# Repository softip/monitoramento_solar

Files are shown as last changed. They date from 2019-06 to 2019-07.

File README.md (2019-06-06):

# Monitoramento Solar

Matéria: IE309X 

Nome                       |RA	 
---------------------------|------
Eloísa A. N. Matthiesen	   |208929
Rafael Augusto Pedriali    |190742
Dimas Augusto Mendes Lemes |163660 
Ivan Paulino Pereira       |262125	

## Introdução 
Diante das novas formas de se usarem os dispositivos eletrônicos, novas tecnologias foram sendo desenvolvidas e adaptadas para as novas funcionalidades. A busca por maiores taxas de transmissão de dados, visando formas de conexão que minimizem custos de projeto, que diminuam a necessidade de alta potência na transmissão e aumentem as áreas de cobertura sendo confiáveis vêm produzindo resultados nos meios industrial e acadêmico. Estas tecnologias estão relacionadas ao conceito de Internet das Coisas. 

A Internet das Coisas, representada pela sigla IoT (Internet of Things), é definida de acordo com a União Internacional das Telecomunicações como uma infraestrutura global que habilita serviços avançados por meio da interconexão entre coisas, ditas físicas ou virtuais, com base nas tecnologias de informação e comunicação. Ou seja, a ideia é conectar coisas, objetos do dia-a-dia, dotando-os de capacidade de processar dados. Dessa forma, uma solução em IoT deve atender a três pré-requisitos. São eles: Reconhecimento de dados, Conexão a uma rede e a Capacidade de processar os dados sem que haja interferência humana. 
A aplicação de IoT pode trazer benefícios aos cidadãos, à gestão pública, como questões envolvendo segurança, transporte e eficiência energética, que também é benéfica ao meio ambiente. A questão ambiental também é um fator relevante devido às fontes de energia renováveis, dentre elas a energia solar. 
A energia solar pode ser usada como fonte de energia elétrica e tem a vantagem de ser uma das mais limpas formas de geração de energia existentes no mundo. É utilizada em tecnologias como arquitetura solar, fotossíntese artificial, aquecimento solar, energia heliotérmica e energia solar fotovoltaica. Especificamente no caso da energia solar fotovoltaica, a luz do sol é captada por meio de painéis solares que tem por finalidade realizar a conversão da energia luminosa em energia elétrica. Nesse processo é possível criar uma rede IoT em que os painéis solares estejam conectados a dispositivos de comunicação que traduzam, por exemplo, ao consumidor a capacidade de geração de energia elétrica do sistema, buscando minimizar custos. 

## Objetivo 
Desenvolver uma Rede de Sensor Sem Fio (RSSF) para monitoramento da geração de energia em painéis solares. Serão coletados os valores da tensão e corrente, enviando-os para um banco de dados, sendo possível ter o completo gerenciamento dos dados coletados. A comunicação será realizada por meio de módulos de comunicação BE900.

## Material 

Item |Uni |Quant |Descrição                          |Unitário   |Total
:---:|:--:|:----:|-----------------------------------|----------:|--------:
1    |UN  |2     |Módulos de comunicação BE900       |R$   180,00|R$ 360,00
2    |UN  |1     |UARTsBee                           |R$   127,00|R$ 127,00
3    |UN  |2     |Antenas omnidireccional de 2,15 dBi|R$    29,00|R$  58,00
4    |UN  |1     |Placa de desenvolvimento DK 107    |R$   165,00|R$ 165,00
5    |UN  |1     |Raspberry Pi                       |R$   290,00|R$ 290,00
6    |UN  |1     |Sensor Allegro ACS712              |R$    26,90|R$  26,90
7    |UN  |1     |Amplificador LM324                 |R$    12,00|R$  12,00
### Total                              R$ 1.038,90 

## Cronograma
Ativid. \ Mês                      |Março |Abril |Maio  |Junho
-----------------------------------|:----:|:----:|:----:|:----:
Estudo do Tema                     |X     |      |      |
Elaboração do Projeto              |X     |      |      |
Seleção e Obtenção dos Componentes |X     |      |      |
Montagem                           |X     |X     |X     |  
Desenvolvimento do Software        |X     |X     |X     |
Testes                             |      |      |X     |
Elaboração do Relatório Final      |      |      |      |X
Apresentação Final                 |      |      |      |X

## Questão a)

### Nível 7 – Negócio
O negócio contemplado nesse projeto foi a geração fotovoltaica construída na Unicamp, um subprojeto do Campus Sustentável. Ao todo será instalado 573 kWp de geração no campus, focaremos na microgeração instalada na FEEC - Faculdade de Engenharia Elétrica e de Computação, com 97 kWp.
### Nível 6 – Exibição
Nesse nível irá apresentar gráficos para os estudantes e funcionários da Unicamp, mostrando o nível de geração da FEEC e o quanto isso significa no uso total da energia do campus. Nesse nível é necessário definir quais são as regras do negócio, quais os alarmes e alertas que serão criados durante o projeto.
### Nível 5 – Abstração
A abstração é feita com a ajuda de um especialista, qual a tensão nominal da placa fotovoltaica, qual a eficiência da mesma? Essas questões são resolvidas utilizando um especialista. No caso do projeto, o especialista pode ser algum professor com conhecimento na área que pode ajudar o grupo.
### Nível 4 – Storage
O armazenamento dos dados, no primeiro momento, será feito localmente, mas tendo a possibilidade de enviar os dados para a nuvem. É preciso definir a quantidade de dados que será armazenada e com qual frequência.
### Nível 3 – Borda
O elemento de borda é responsável pela conexão da RSSF à Internet. Ele será realizado através de uma Raspberry Pi 3.
### Nível 2 – Conectividade
A conectividade será feita por meio de uma RSSF, com módulos de comunicação compostos por um microcontrolador Atmega328 e um transceptor CC1101. Uma placa de desenvolvimento DK107 no Nó Sensor e um programador UARTsBee para a Estação Rádio Base (ERB).
### Nível 1 – Nó Local Sensor/Atuador
Utilizaremos a plataforma Radiuino para criar os firmwares dos Nós. Para medir a tensão da placa será usado o DK107, em conjunto com um divisor de tensão, e a corrente será medida através de um sensor de efeito hall, Allegro ACS712.
Nível 0 – Coisas
A coisa desse projeto é a placa fotovoltaica, utilizada na microgeração da FEEC.

## Questão b)

### b.1) 
As variáveis da "coisa" que devem ser medidas são a corrente e a tensão do painel fotovoltaico durante o tempo, para assim poder calcular a energia produzida pela mesma.

### b.2) 
Primeiramente, são analisadas as especificações dos painéis solares, pois é necessário saber a faixa de operação do equipamento para a adequada elaboração e desenvolvimento do projeto.

Painel                              |Potência (W)|Tensão (V)|Corrente (A)
------------------------------------|:----------:|:--------:|:----
Yingli JS150                        |150         |18.5      |8.12
Kyocera KD140SX                     |140         |17.7      |7.91
Komaes KMP150                       |150         |18.28     |8.21
Canadian Solar CS6K 260P            |260         |30.40     |8.56
Canadian Solar CS6K 275P            |275         |31        |8.88
UPSolar M150P                       |150         |18.06     |8.07
UPSolar M315P                       |315         |36.5      |8.63

Com esta tabela é possível dimensionar um array  de placas que pode para ser projetado seguindo as especificações do sensor Allegro ACS712, o qual é apresentado no próximo item.
 
### b.3) 
Após realizar uma pesquisa de mercado foi observado que a melhor opção para poder realizar as medidas da corrente é com o sensor Allegro ACS712, o qual pode ser visto na figura a seguir.


 
Este sensor é classificado como invasivo, ou seja, é necessário abrir o circuito para fazer a medição.  Além disso, ao adicioná-lo ao circuito provoca uma baixa queda de tensão durante a medição, devido a sua resistência interna ser de apenas 1,2 mOhm. Possui fundo de escala de -30 A até 30 A tanto para corrente contínua como para alternada, com uma sensibilidade de aproximadamente 0,066 mV/A. A medição ocorre por meio do efeito hall para detectar o campo magnético gerado pela corrente.
 
A de tensão a ser medida será realizada diretamente, mas como a entrada pino de medição não deve possuir uma tensão maior do que 5V. Então será realizado um divisor de tensão para abaixar a tensão gerada. Este circuito é isulatrado a fingura a seguir.



O capacitor tem o objetivo de eliminar possíveis ruídos na medição.

Outra medida a ser informada é a temperatura, pois apesar do aumento na irradiação solar sobre a placa fotovoltaica fornecer mais energia, o aumento da temperatura da placa danifica-a. O sensor utilizado para a medição é o LM35DZ encapsulado (proteção contra fatores adversos, como a chuva).

### b.4) 
O circuito esquemático do sensor é apresentado na figura a seguir



Onde,
Vcc, é o pino de alimentação do circuito, em que será utilizado uma bateria para poder alimentá-lo.
Viout é o pino que informa os dados da corrente e tensão medidos
GND é o pino terra
Os pinos IP+ e IP-  conectam-se em série ao circuito que deverá ser medido.

### b.5) 
No site da Allegro, empresa responsável pela fabricação do sensor, há uma página de FAQ. Perguntaram qual a menor corrente que pode ser medida pelo ACS712, foi respondido que a sua resolução é determinada pelo nível de ruído, mostrando assim uma tabela das características de filtros que podem ser aplicadas.



Dependendo do valor da corrente que será necessário medir, é necessário alterar o capacitor utilizado.

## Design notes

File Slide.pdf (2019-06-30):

# Monitoramento Solar

### Disciplina: IE309 - X

Nomes: Eloísa A. N. Matthiesen | RA: 208929
Rafael Augusto Pedriali | 190742
Dimas Augusto M. Lemes | 163660
Ivan Paulino Pereira | 262125

# Contextualização

- Problema: Elevado gasto com energia elétrica nas IFs, cerca de R$ 430.000.000,00 e na Unicamp R$ 25.000.000.
- Motivo: Equipamentos ineficientes, práticas de instalações inadequadas, uso e manutenção de equipamentos e falta de cultura para uso eficiente e racional.
- Solução: Projeto do Campus Sustentável da Unicamp na FEEC.
Subprojeto: Geração de energia através de painéis fotovoltaicos.
- Proposta de uso de IoT como solução: Auxiliar na tomada de decisão para expansão e/ou manutenção do parque de geração de energia fotovoltaica.

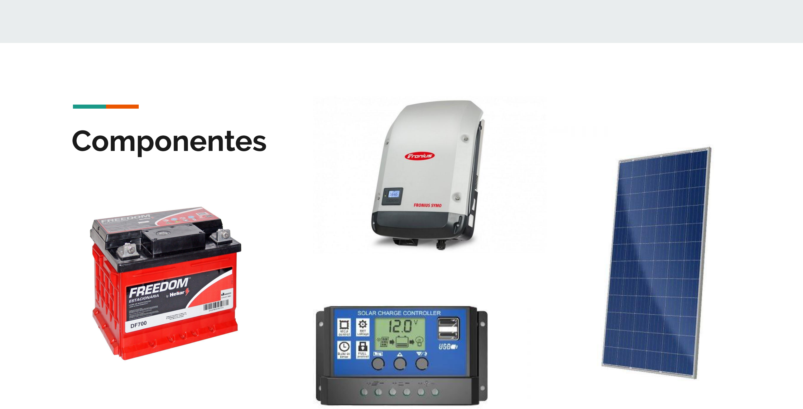
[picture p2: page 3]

# Componentes

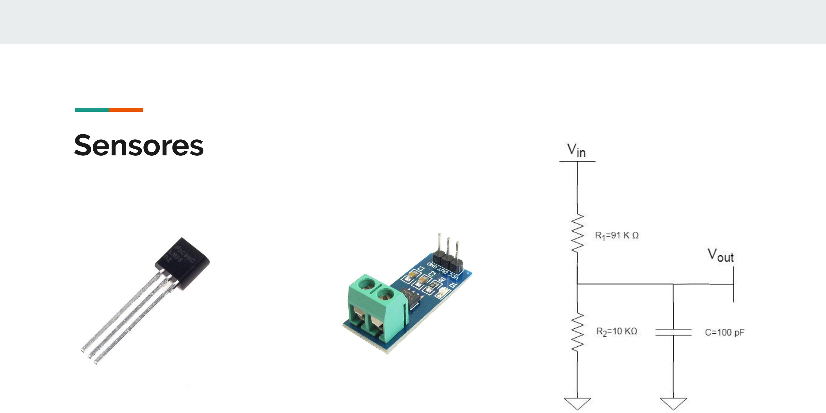
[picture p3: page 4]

# Sensores

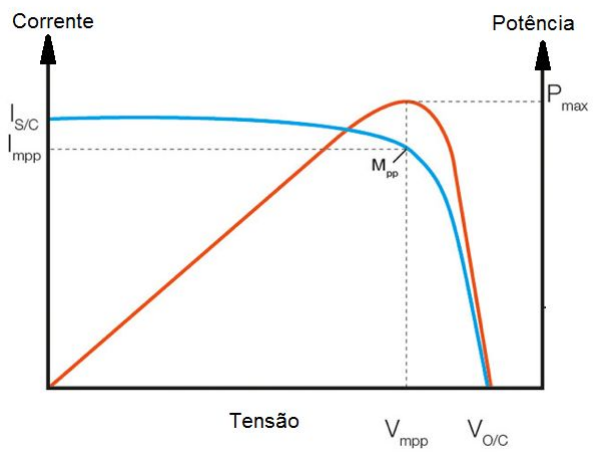
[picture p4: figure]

# MPPT:

# Esquemático

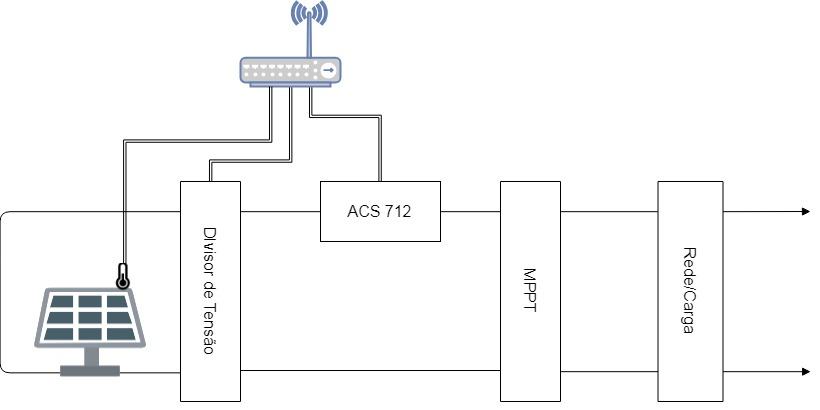
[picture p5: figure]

# Modelo de Referência

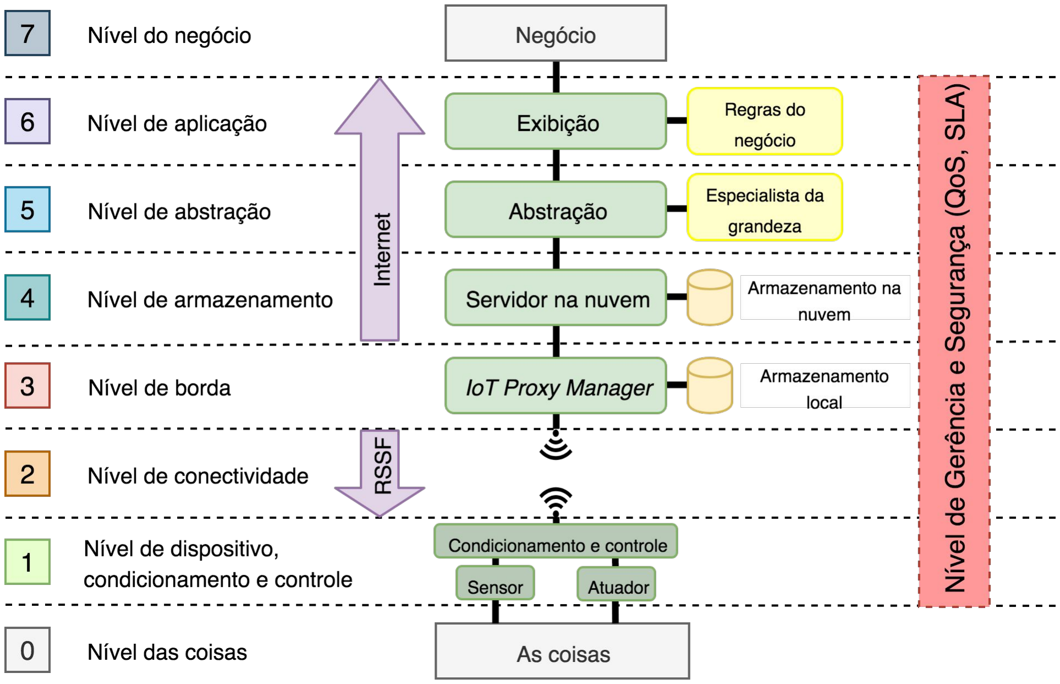
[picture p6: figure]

Figura 1: Modelo de Referência para aplicações IoT.

# Primeiro Ciclo - Negócio

- Monitoramento de painéis fotovoltaicos visando economia de energia;
- Subprojeto do Campus Sustentável da Unicamp na FEEC;
- 573 kWp de geração fotovoltaica, dos quais 97 kWp serão gerados na FEEC;
- A coisa utilizada no projeto é o painel fotovoltaico;
- Os parâmetros do painel a serem analisados serão a corrente, a tensão , tempo e temperatura.
- Por ano, a UNICAMP gasta R$ 25 milhões em energia, com os painéis instalados, o campus vai economizar R$ 500 mil por ano.

# Regras de Negócio

- Atualmente, as placas fotovoltaicas estão em funcionamento e há o inversor mostrando a potência gerada em tempo real. Não estão disponíveis gráficos diários da geração ou alarmes.

Premissas:
- Tornar as medidas online
- Calcular a energia gerada.

Operações/informações que serão atendidas:
- O negócio espera facilitar o monitoramento das placas, enviando os valores de tensão, corrente e temperatura.

# Segundo Ciclo – Especificação: Top-Down

Neste ciclo, são estabelecidos seis níveis que ligam o negócio (Nível 7) e a coisa (Nível 0), segundo o modelo de referência por um approach top down.

# Terceiro Ciclo – Implementação: Bottom-up

Neste ciclo é feita a utilização dos níveis mencionados anteriormente. No entanto, agora com abordagem bottom up. Ou seja, partindo dos níveis de números menores (mais perto da coisa) até os de números maiores (mais perto do negócio).

# Nível 6 - Exibição

- Top-down: Utilização de gráficos mostrando o onde serão exibidos níveis de tensão, corrente, temperatura e potência. A quantidade de energia produzida.
Haverá alarmes quando a potência da placa chegar em valores não condizentes com a sua operação.
- Bottom-up: Para exibição dos dados foi
desenvolvido um sistema web que possibilita
consultar a tensão, a corrente e a potência dos

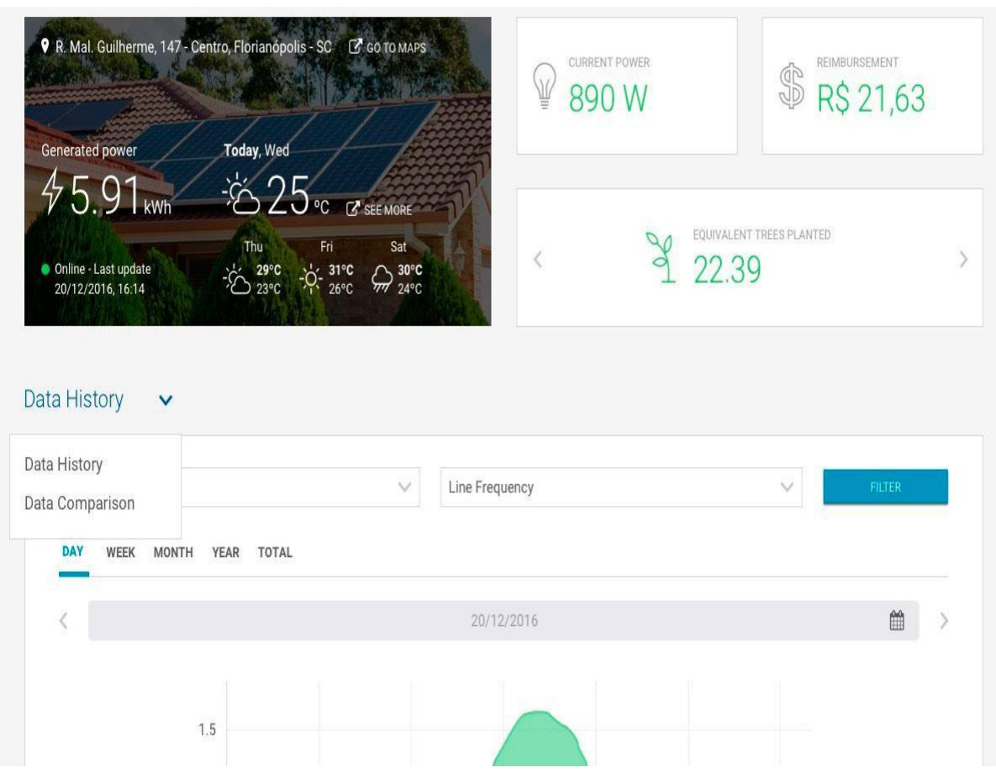
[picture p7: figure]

painéis solares. | Figura 2: Exemplo de relatório de visualização de dados dos painéis WEG que utilizam a tecnologia de IoT desenvolvida pela IBM

# Nível 5 - Abstração

- Top-down: Participação de um especialista no tema do projeto. Definição dos parâmetros da operação, quais são os limites da rede de energia e qual o seu
comportamento | esperado. | Será | necessário | a
eliminação dos outliers. Análise estatística dos dados.
- Bottom-up: Os limites são determinados pelo especialista do negócio e pelos fabricantes dos painéis fotovoltaicos. Se a potência medida estiver abaixo da especificada, o alerta, então é emitido.

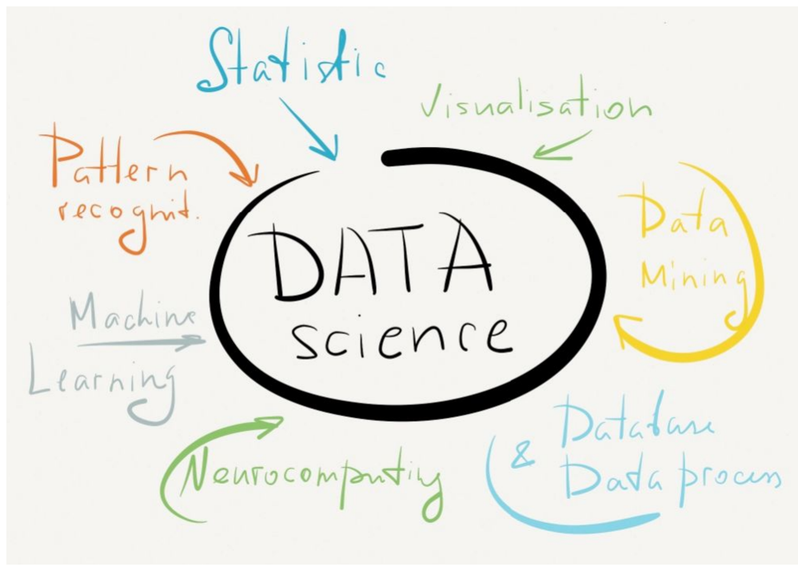
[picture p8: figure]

Figura 3: Possíveis métodos e técnicas na abstração de dados

# Nível 4 - Storage

- Top-down: Os dados serão armazenados localmente e na nuvem. Serão armazenados: A tensão, corrente, temperatura, RSSI e potência.
- Bottom-up: Para o armazenamento de dados
será utilizado um banco de dados MySQL, tendo
em vista o volume dos dados e a pouca

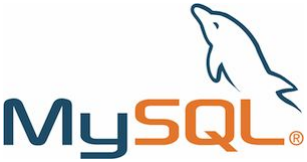
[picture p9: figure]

necessidade de atualização dos deles. | Figura 4 : Banco de dados utilizado.

# Nível 3 - Borda

- Top-down: O elemento de borda irá receber as informações do sensores, realizar a média dos dados coletados e fazer o armazenamento localmente até o envio dos dados para a nuvem, por cabo USB, Ethernet ou WiFi. O elemento de borda será alimentado por uma fonte 5V conectada a rede de energia.
- Bottom-up: Elemento de borda será uma Raspberry Pi 3, e ERB enviando os dados da comunicação para o computador.

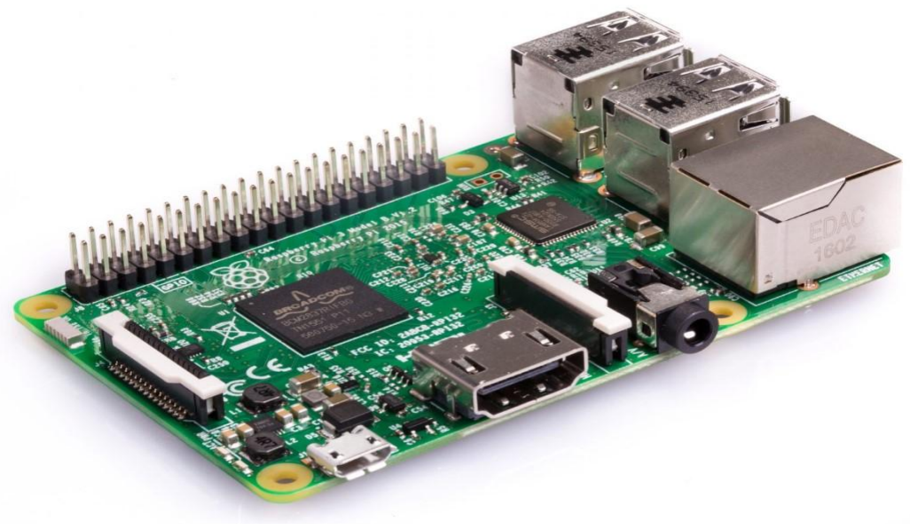
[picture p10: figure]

Figura 4 : Exemplo de uma Raspberry Pi 3 Model B.

# Nível 2 - Conectividade

- Top-down: A antena da ERB consegue realizar a cobertura do nó sensor, havendo apenas um enlace entre a ERB e o nó sensor. A transmissão será feita por radiofrequência utilizando a frequência 915MHz.
- Bottom-up: Será utilizada uma Rede de Sensor Sem Fio (RSSF) com módulos de comunicação BE900 e uma placa de desenvolvimento DK107 no nó sensor. Os módulos de comunicação possuem o transceptor CC1101 e o microcontrolador ATmega328.

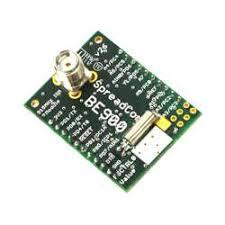
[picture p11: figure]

Figura 5: Módulo de Comunicação BE900.

# Nível 2 - Conectividade

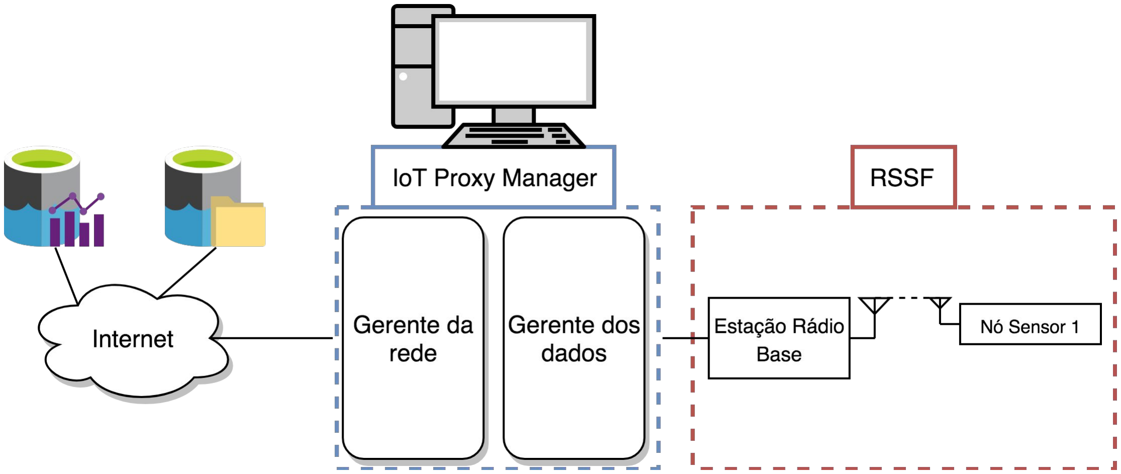
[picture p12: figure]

Figura 6 : Exemplo de uma RSSF completa para IoT.

# Nível 1 - Nó Local Sensor/Atuador

- Top-down: O nó sensor ficará junto às placas na área
de microgeração da FEEC. Haverá apenas um nó sensor que será alimentado por meio de bateria.
- | Bottom-up: | Será | utilizado | uma | placa | de
desenvolvimento DK107, um divisor de tensão para a medição da tensão do painel, um sensor medidor de corrente Allegro ACS712 e um sensor de temperatura, o LM35.

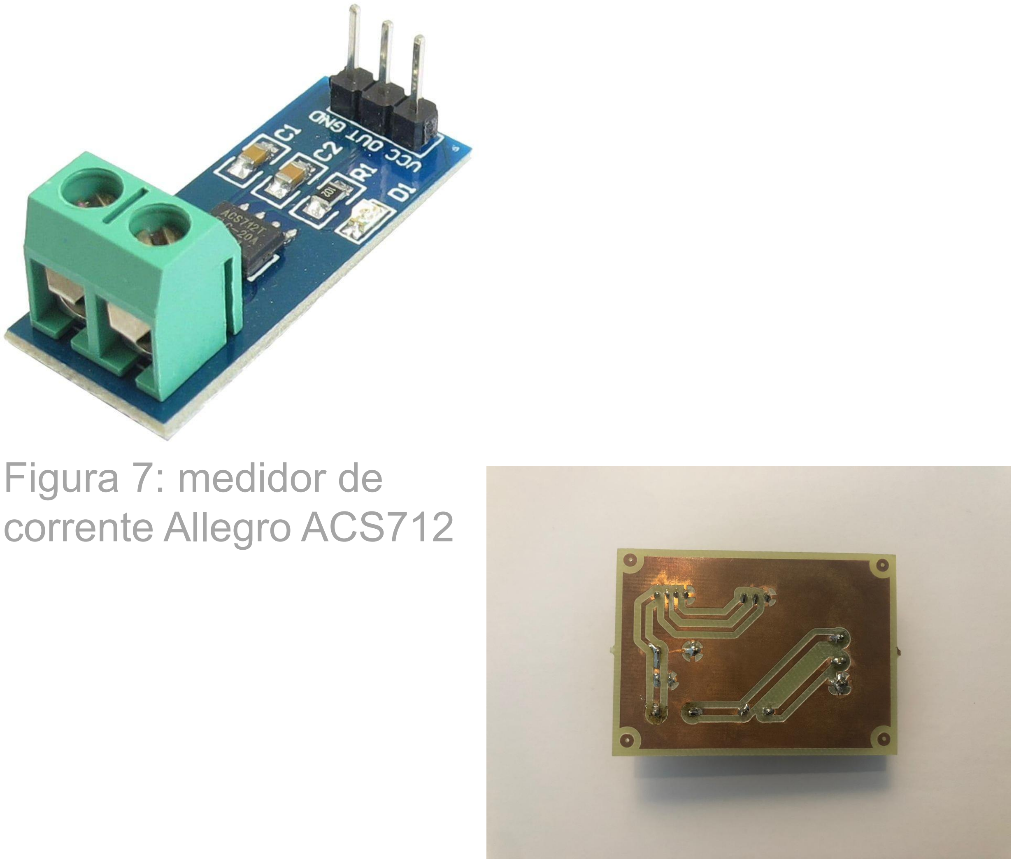
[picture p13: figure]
Figura 7: medidor de corrente Allegro ACS712

Figura 8: Placa projetada

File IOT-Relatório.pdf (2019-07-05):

Universidade Estadual de Campinas Departamento de Engenharia Elétrica e de Computação

## IE309 - Internet Das Coisas: Fundamentos e Oficina Monitoramento Solar

Dimas Augusto Mendes Lemes | 163660
Eloisa A. N. Matthiesen | 208929
Ivan Paulino Pereira | 262125
Rafael Augusto Pedriali | 190742

### Campinas Junho de 2019

# Lista de Figuras

1.1 Mapa de irradiação solar no Brasil (GONCALVES et al., 2018) | | 3
1.2 Exemplo de geração solar distribuída (PEREIRA, 2019) | | 3
1.3 Exemplo de uma usina solar fotovoltaica | | 4
1.4 No lado esquerdo a matriz energética brasileira instalada atualmente e do
lado direito a previsão de expansão para o ano de 2030 | | 5
3.1 Curva de atuação do painel fotovoltaico | | 9
3.2 Diagrama dos três ciclos | 10
3.3 Conjunto de painéis solares | 12
3.4 Inversor de frequência | 13
3.5 Controlador de carga | 14
3.6 Bateria estacionária | 14
3.7 Diagrama de conexão entre os níveis do modelo de referência | 17
3.8 Placa projetada para execução do monitoramento com a ajuda do SATE. . 21
3.9 Módulo de comunicação BE900 | 22
3.10 Raspberry Pi 3 | 23
3.11 Sensor de corrente Allegro ACS712 | 23
3.12 Circuito esquemático do sensor de corrente | 24
3.13 Divisor de tensão | 25
3.14 LM35 não encapsulado | 25
3.15 Esquema de conexão dos sensores ao sistema de geração de energia solar
fotovoltaica | 26
3.16 Esquema do circuito impresso | 27
3.17 Circuito impresso pronto | 27
3.18 Diagrama em blocos da estrutura da rede | 28
3.19 Elementos da rede e suas respectivas camadas | 30
3.20 Framework | 31
3.21 Fluxograma | 32
3.22 Modelo Entidade e Relacionamento | 34
3.23 Diagrama de casos de uso | 35
3.24 Diagrama de atividades | 37
3.25 Dashboard do sistema web | 38
3.26 Alertas de falhas | 39
3.27 Tela de cadastro de painéis fotovoltaicos | 40
4.1 Ambiente com a apresentação dos dados monitorados | 42

# Lista de Tabelas

1.1 Expansão da matriz energética brasileira | 5

3.1 Classificação com relação a eficiência com a proporção dos painéis produzidos 16 3.2 Nível de ruído e resolução vs. Capacitância de filtragem e resolução de
largura de banda | 20
3.3 Nível de ruído e resolução vs. Capacitância de filtragem e resolução de
largura de banda | 24

# Sumário

1 Introdução | 1
2 Objetivo | 6
3 Desenvolvimento | 7
4 Resultados | 41
5 Conclusão | 43
Referências bibliográficas | 44

# Capítulo 1

# Introdução

Diante das novas formas de se usarem os dispositivos eletrônicos, novas tecnologias foram

sendo desenvolvidas e adaptadas para as novas funcionalidades. A busca por maiores taxas

de transmissão de dados, visando formas de conexão que minimizem custos de projeto,

que diminuam a necessidade de alta potência na transmissão e aumentem as áreas de

cobertura sendo confiáveis vêm produzindo resultados nos meios industrial e acadêmico.

Estas tecnologias estão relacionadas ao conceito de Internet das Coisas.

A Internet das Coisas, representada pela sigla IoT (Internet of Things), é definida

de acordo com a União Internacional das Telecomunicações como uma infraestrutura

global que habilita serviços avançados por meio da interconexão entre coisas, ditas físicas

ou virtuais, com base nas tecnologias de informação e comunicação. Ou seja, a ideia é

conectar coisas, objetos do dia-a-dia, dotando-os de capacidade de processar dados. Dessa

forma, uma solução em IoT deve atender a três pré-requisitos. São eles: Reconhecimento

de dados, Conexão a uma rede e a Capacidade de processar os dados sem que haja

interferência humana.

A aplicação de IoT pode trazer benefícios aos cidadãos, à gestão pública, como questões

envolvendo segurança, transporte e eficiência energética, pois permite trazer ao usuário

um poder de decisão sobre o ambiente abordado com muito mais agilidade e facilidade.

Neste projeto a aplicação IoT abordada é voltada sobre sistemas de geração de energia

solar fotovoltaica.

A energia solar fotovoltaica é uma das mais limpas formas de geração de energia

existentes no mundo, a luz do sol é captada por meio de painéis solares que tem por

finalidade realizar a conversão da energia luminosa em energia elétrica. Nesse processo é

1

CAPÍTULO 1. INTRODUÇÃO | 2

possível criar uma rede IoT em que os painéis solares estejam conectados a dispositivos

de comunicação que traduzam, por exemplo, ao consumidor a capacidade de geração de

energia elétrica do sistema, buscando minimizar custos e identificar problemas na geração

da energia.

## 1.1 Matriz energética brasileira

Atualmente a maior fonte de energia elétrica do sistema elétrico brasileiro é sistema hidro-

elétrico, e apresenta-se de forma predominante, em seguida vem as termelétricas, dando

sequencia às energias renováveis como a eólica, solar e biomassa. Embora a energia solar

tenha uma proporção muito pequena de geração sobre o sistema elétrico nacional, ela

possui uma grande previsão de expansão, proporcionado pelo grande potencial de energia

solar incidente no território brasileiro, e pela evolução da tecnologia fotovoltaica tanto

em grandes centrais geradoras fotovoltaicas, quanto na geração distribuída. A Figura 1.1

apresenta o mapa de irradiação solar direta no Brasil, note que este país possui grande

potencial de energia solar (GONCALVES et al., 2018).

A geração solar distribuída ocorre pela geração própria da energia dos consumidores

e que também estão conectados à rede elétrica, além disso, ela é responsável por grande

parte da expansão da energia solar mundial. No Brasil foi instituída em 2012, através

da resolução 482 da ANEEL. Ela permite que consumidores de energia possam gerar a

própria energia através de fontes renováveis e transferir a energia excedente à rede das

concessionárias de distribuição. Isto é, sistema de compensação, conhecido como Net

Metering, ou medição líquida. Quando a geração da energia for maior do que o consumo,

o excedente será injetado na rede de distribuição, gerando créditos energéticos. Deste

modo, quando não há geração, ou quando a energia gerada não for suficiente para suprir

todo o consumo, a energia será fornecida normalmente pela concessionária. Ao final

do mês, o valor a ser pago corresponde à diferença da geração e do consumo. Caso o

saldo da geração seja positivo, os créditos energéticos podem ser utilizados nos 60 meses

subsequentes. Esses créditos também são usados para compensar a fatura de energia

em outros pontos dentro da área de concessão de uma mesma distribuidora (PEREIRA,

2019). A Figura 1.2 apresenta um ótimo exemplo da geração solar distribuída.

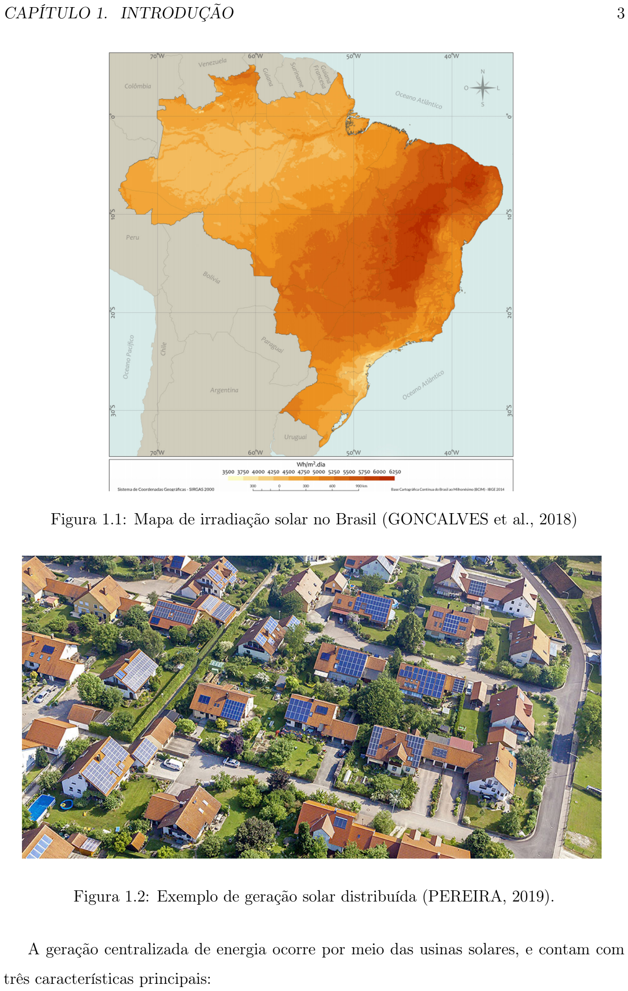
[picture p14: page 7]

CAPÍTULO 1. INTRODUÇÃO | 3

Figura 1.1: Mapa de irradiação solar no Brasil (GONCALVES et al., 2018)

Figura 1.2: Exemplo de geração solar distribuída (PEREIRA, 2019).

A geração centralizada de energia ocorre por meio das usinas solares, e contam com

três características principais:

CAPÍTULO 1. INTRODUÇÃO | 4
- Gerar energia para o mercado livre
- Gerar energia para o mercado cativo, por meio da participação em leilões de energia
- Autogerar energia para grandes consumidores.

A geração centralizada tem sua produção do sistema energético aplicado em um am-

biente particular, sem terceiros ou intermediários permitindo serem empregadas como for

desejado.

Sendo uma das finalidades da geração centralizada o leilão da energia produzida, é

necessária a execução do processo para a realização dos leilões. Que vão desde a inscrição

e habilitação até a finalização do acordo. As usinas solares, diferente da geração centra-

lizada, não demandam a execução de leilão para sua distribuição. O sistema de geração

de energia solar em construção da UNICAMP é um exemplo (CPFL, 2017).

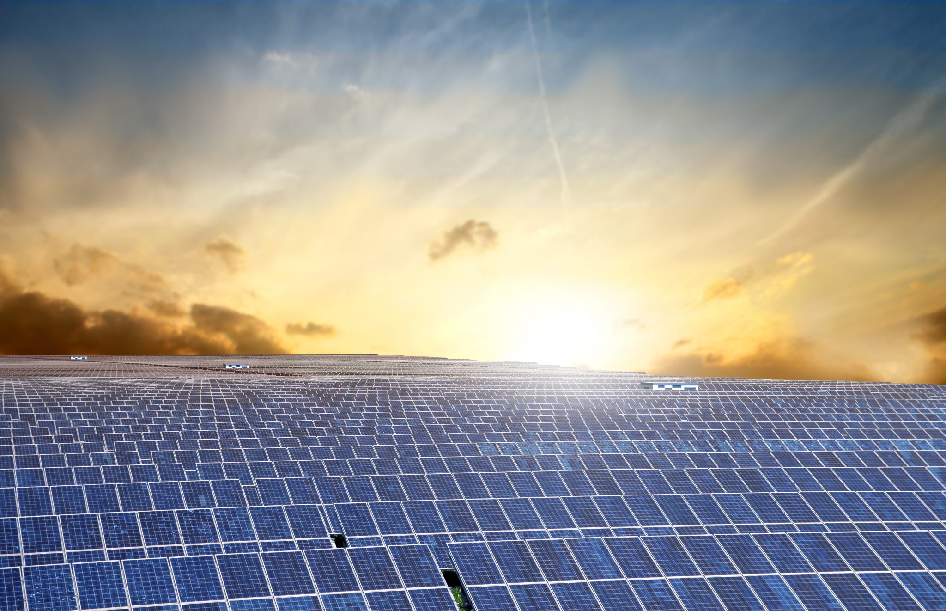
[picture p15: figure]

Figura 1.3: Exemplo de uma usina solar fotovoltaica.

A previsão de expansão da geração elétrica no Brasil para o ano de 2030 está apresen-

tado na Tabela 1.1. Observe como a geração solar centralizada e distribuída possuem o

maior percentual de crescimento comparado às outras fontes de geração de energia. Outro

gráfico muito interessante está apresentado na Figura 1.4, onde mostra a matriz energé-

CAPÍTULO 1. INTRODUÇÃO | 5
Fonte | 2014 (TWh) | 2030 (TWh) | Participação em 2030 (%) | Incremento (TWh) | Potência Adicional (GWp) | Crescimento (%)
Hidráulica Eólica Solar-Cent. Solar-Dist. Biomassa Outras | 407 697 61 % 290 66 64 % 12 105 9 % 93 26.5 108 % 0 26 2 % 26 14.8 493 % 0 9 1 % 9 5.1 6321 % 41 134 12 % 93 4.2 28 % 164 180 15 % 16 -
Total | 624 1151 527

Tabela 1.1: Expansão da matriz energética brasileira.

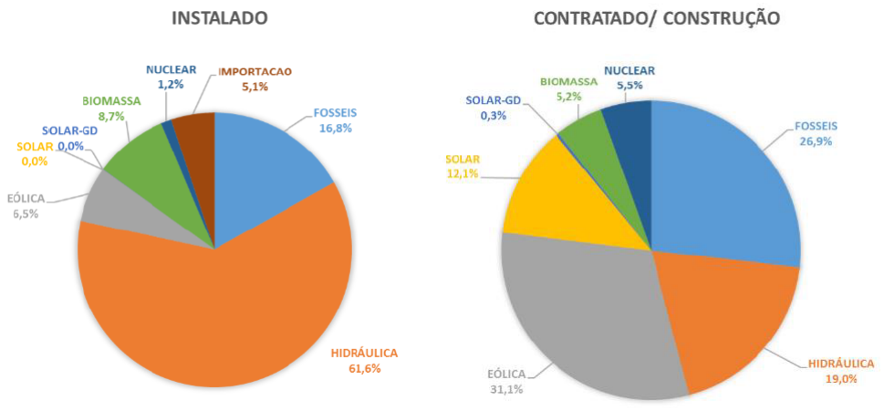
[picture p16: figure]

Figura 1.4: No lado esquerdo a matriz energética brasileira instalada atualmente e do lado direito a previsão de expansão para o ano de 2030.

tica atual e em construção. Note como as fontes renováveis eólica e solar apresentam um

crescimento expressivo da matriz energética brasileira (GONCALVES et al., 2018).

# Capítulo 2

# Objetivo

O objetivo deste trabalho é desenvolver uma Rede de Sensores Sem Fio (RSSF) para dis-

positivos capazes de monitorar dados de painéis solares. Os dados coletados são corrente,

tensão e temperatura do painel, os quais são transmitidos pelo ambiente sem fio para um

banco de dados, sendo possível ter o completo gerenciamento dos dados coletados em um

ambiente online. O banco de dados projetado é capaz de monitorar diversos dispositi-

vos de medição ao mesmo tempo, independente das marcas e modelos dos equipamentos

utilizados nos sistemas de geração fotovoltaica.

6

# Capítulo 3

# Desenvolvimento

A dependência da energia elétrica na sociedade atual é uma necessidade em que geral-

mente é suprida pelos sistemas elétricos, entretanto, alguns lugares não possuem acesso ao

sistema devido a sua dificuldade de acesso como em áreas rurais remotas e em pequenas

comunidades afastadas onde custo de se conectar à rede seria elevado. Dessa forma, o

fornecimento de energia para estas comunidades pode ser realizada com outras formas

mais viáveis, como é o caso da energia solar fotovoltaica. Além deste aspecto, a energia

solar tem ganhado espaço mundialmente por ter uma geração limpa, inovadora, com fá-

cil implementação e inclusive pela redução do valor de mercado, tornando-se quase que

popular e com um ótimo custo-benefício.

O desenvolvimento da tecnologia de painéis solares está evoluindo continuamente e

apresentando um elevado potencial de venda para empresas com elevado gasto energé-

tico, para pessoas comuns que queiram realizar economia em suas contas de luz e para

comunidades isoladas. Então este trabalho busca complementar o acesso a informação

do proprietário sobre seu sistema de geração de energia fotovoltaica independente de sua

localização e monitorados por uma rede de sensores sem fio. Esta rede notificará ao

proprietário a identificação sobre possíveis falhas do sistema.

## 3.1 Sistema de geração de energia solar fotovoltaica

Atualmente existem dois sistemas distintos de geração de energia solar fotovoltaica, o

on-grid e o off-grid, discutidos brevemente a seguir.

7

CAPÍTULO 3. DESENVOLVIMENTO | 8

Sistema off-grid ou isolados, como o nome informa, é um sistema fotovoltaico separado

de qualquer outro sistema de distribuição. A energia que é produzida pelos módulos

fotovoltaicos é basicamente armazenada em um conjunto de baterias, a principal vantagem

é a facilidade de implementação, não sendo necessário ter autorização da companhia

elétrica para implementar.

Sistema on-grid ou sistema fotovoltaico de microgeração distribuída é um sistema

conectado à rede de distribuição de energia, portanto, pode ser considerada como uma

pequena parte do grande sistema de geração integrado. Do ponto de vista econômico, este

sistema não precisa ser conectado à um conjunto de baterias trazendo uma grande eco-

nomia ao projeto, basta apenas conectar o arranjo de painéis a um inversor de frequência

e em seguida levar a energia para a rede elétrica (VILLALVA; GAZOLI, 2015).

Curva de atuação do painel

Os painéis solares têm a capacidade de fornecer uma potência máxima. Seu valor é

definido em projeto. No entanto ao conectar uma placa à carga, por exemplo de 60 W,

dificilmente o painel estará fornecendo a potência de 60 W. Para que o painel entregue a

máxima potência fornecida pelo fabricante, é necessário que o painel esteja atuando em

um ponto específico, isto é, o MPPT (Maximum Power Point Tracker ) ou Rastreador de

Máxima Potencia do Painel. A curva de atuação em I × V e P × V de uma placa solar

fotovoltaica é esboçado na Figura 3.1 e os pontos definidos no gráfico correspondem a:

- Is/c: Corrente de curto-circuito, é a corrente máxima que o módulo oferece.
- Vo/c: Tensão de circuito aberto, é a tensão máxima oferecida pelo módulo.
- Impp: Corrente de máxima potência, é o ponto de operação de máxima corrente de

operação do módulo.

- Vmpp: Tensão de máxima potência, é a tensão máxima potência apresentada durante

a operação do módulo.

Figura 3.1: Curva de atuação do painel fotovoltaico.

Neste gráfico a curva em azul corresponde aos possíveis valores de atuação do painel

fotovoltaico, e a curva em vermelho é seu correspondente em potência. Para que o painel

atue sobre o MPPT é necessário adicionar ao sistema otimizadores de potência, que são

projetados especificamente para forçarem a os painéis a atuarem sobre este ponto. Os

otimizadores estão presentes em alguns equipamentos específicos para sistemas de geração

de energia solar, como o inversor de frequência e o controlador de carga (VILLALVA;

GAZOLI, 2015).

Cálculo de árvores cultivadas

O número de árvores cultivadas pode parecer algo um pouco abstrato e intangível, mas é

uma métrica que ajuda a compreender os benefícios ecológicos de um projeto de geração

de energia solar fotovoltaica, a qual está relacionada às energias sustentáveis. Diversas

fontes de energia estão ligadas a queima de combustíveis fósseis, como carvão, petróleo,

gás natural. Dessa forma, o aumento da quantidade de sistemas de geração de ener-

gia solar reduz indiretamente a necessidade das energias produzidas a partir da queima

combustíveis fósseis.

O calculo equivalente ao número de árvores cultivadas é obtido diretamente a partir

da energia elétrica gerada sobre um período de tempo multiplicado pelo coeficiente de árvores cultivadas (5, 04 × 10⁻⁴ árvores/KWh) considerando o fator de emissão médio de

CO2 em 0.1258KgCO2/KWh (MÜLLER, 2019).

## 3.2 Metodologia dos três ciclos

Esta seção descreve detalhadamente a metodologia dos três ciclos (Negócio, Especificação,

Implementação) em um sequência lógica da estrutura do projeto para a implementação

do IoT sobre o cenário proposto.

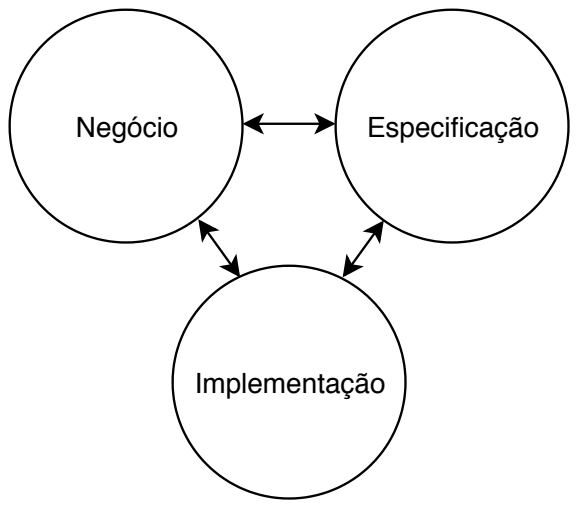
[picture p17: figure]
Negócio; Especificação; Implementação

Figura 3.2: Diagrama dos três ciclos

### 3.2.1 Primeiro ciclo, Negócio

O Negócio

A energia elétrica é indispensável para o desenvolvimento da humanidade, para geração

de bens e serviços e para conforto e segurança da sociedade. De acordo com a ANEEL, o

consumo de energia é um dos principais indicadores do desenvolvimento econômico e do

nível de qualidade de vida de qualquer sociedade (ANEEL, 2019).

De acordo com levantamentos realizados pelo Ministério da Educação os gastos com

energia elétrica nas instituições de ensino superior publicas somam cerca de 500 milhões de

reais. Na Universidade Estadual de Campinas - UNICAMP, o consumo de energia elétrica

é cerca de 25 milhões de reais por ano e corresponde a 25% do custeio da universidade

(CPFL, 2018).

Tendo em vista que o gasto com energia elétrica é elevado nas instituições de ensino

superior e que ele compromete cerca 25% do orçamento de custeio da UNICAMP, a

UNICAMP em parceria com a CPFL elaborou o projeto campus sustentável, que faz

parte de um esforço proposto pela ANEEL para reduzir o consumo de energia elétrica nas

universidades públicas.

A Mini geração fotovoltaica, será instalado 534 kWp de geração fotovoltaica, distri-

buída em 13 locais dentro do campus da UNICAMP, nos seguintes locais: estacionamento

GMU, BCCL, CB, Cepetro, IG, ADM, IC, FEC, IFGW, IQ, FEM, FEA e FEEC. Para re-

alização deste projeto será investido o valor de 3.173.055,20 (três milhões, cento e setenta

e três mil, cinquenta e cinco reais e vinte centavos). Espera-se que esse projeto contribua

com a redução de 1.3% de energia consumida atualmente, ou seja R$ 325.000,00 (trezentos

e vinte e cinco mil reais) por ano (CPFL, 2017). Considerando apenas o valor investido

e o valor da energia gerada, o investimento será quitado em 9.7 anos.

Os fabricantes de painéis fotovoltaicos geralmente fornecem garantia de 25 anos para

o produto. No entanto, dada a ação do tempo eles geralmente perdem a capacidade de

geração de energia. Tal capacidade também é influenciada pela temperatura do painel,

bem como pelos períodos de exposição a luz ao longo dos anos. Além da perda de

capacidade natural dos painéis é possível que ocorra problemas nos terminais de contato

por causas das chuvas e outras intempéries que reduzem a produção de energia elétrica.

Considerando que os gastos de energia elétrica comprometem cerca de 25% do orçamento

de custeio da UNICAMP, que a geração de energia fotovoltaica apresenta-se como uma

alternativa para a redução dos gastos com energia e que o investimento na mini usina

representa um valor considerável em relação a energia produzida, este trabalho pretende

produzir um solução em IoT para monitorar a geração de energia e auxiliar na redução

dos gastos com energia.

A solução irá possibilitar monitorar a energia gerada por cada painel solar, ou con-

junto de painéis, e determinar se existe alguma queda anormal na produção de energia,

representando uma falha com o painel. A identificação da falha precocemente irá auxiliar

na manutenção da produção de energia, bem como irá reduzir os custos de manutenção,

tendo em vista que a solução irá identificar o local exato do problema.

A solução também possibilitará ao longo dos anos estimar, com base na produção de

energia passada, a viabilidade da implantação de novos parques de geração fotovoltaica.

A coisa

Neste projeto a definição das coisas será um sistema de geração de energia solar fotovol-

taica, o qual é composto por painéis solares, inversor de frequência, controlador de carga

e bateria. Com estes equipamentos é possível realizar um monitoramento bem adequado

da tensão e da corrente gerada pelo sistema. Com os dados sendo monitorados, é possível

ter acesso a informação de cada um dos elementos da rede. Com estas informações será

possível identificar com mais facilidade e agilidade possíveis falhas localizadas em suas

posições específicas da rede IoT. Os equipamentos referenciados são detalhados a seguir.

- Painel solar: Os painéis solares são construído por várias células de silício ou fotovol-

taica, as quais geram eletricidade a partir da irradiação solar, na forma de corrente

contínua (DC).

As células fotovoltaicas estão ligadas entre si dentro de cada painel solar e conectadas

a painéis adjacentes usando cabos, semelhante ao da Figura 3.3.

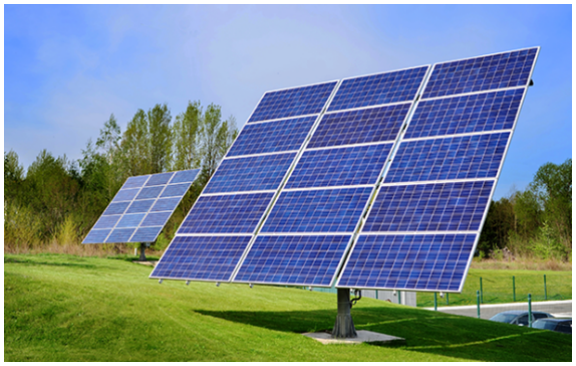
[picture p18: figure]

Figura 3.3: Conjunto de painéis solares.

Obs: O calor não produz energia, é a irradiação solar. Pelo contrário, o calor danifica

os painéis, fazendo-os perder eficiência com o passar do tempo.

A energia gerada depende das condições climáticas, por exemplo, em um dia nu-

blado/chuvoso, a quantidade de energia produzida será menor do que dias enso-

larados. A quantidade de energia luminosa é conhecida como irradiação solar e geralmente é calculada ao longo do dia usando o termo Horas do Sol no Pico (PSH).

O para a localização e tendo em conta a orientação e ângulo de inclinação dos painéis

solares (LUCAS, 2019).

- Inversor de frequência: Os painéis solares geram energia de tensão contínua que

precisa ser convertida em tensão alternada para uso em geral, esta conversão é

realizada pelo inversor de frequência. O sistema pode ser projetado utilizando um

microinversor, cujas especificações de atuação não permitem ligar um grande número

de painéis solares, já os inversores de string permitem ligar vários painéis solares.

Outra característica importante dos inversores é que eles também atuam como oti-

mizadores de potência, em que monitoram e controlam a atuação dos painéis para

garantir que cada painel esteja operando com a máxima eficiência sob todas as

condições (LUCAS, 2019).

Figura 3.4: Inversor de frequência.

- Controlador de carga: Os controladores de carga ficam entre os painéis e as baterias e

são utilizados para controlar a voltagem de entrada nelas a fim de evitar sobrecargas

ou descargas excessivas, otimizar a potência gerada pelos painéis e prolongar a sua

vida útil. Os painéis solares produzem energia proporcional a irradiação de luz

solar, porém as baterias não suportam tal variação. Para solucionar este problema e

também para aprimorar o carregamento das baterias, são utilizados os controladores

de carga (VILLALVA; GAZOLI, 2015).

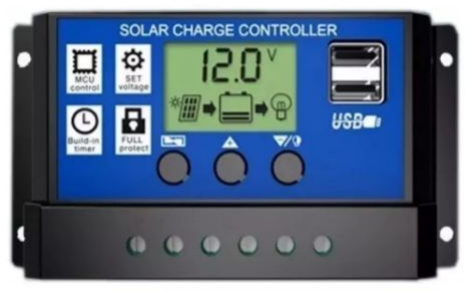
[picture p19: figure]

Figura 3.5: Controlador de carga.

- bateria: As baterias são responsáveis por todo o armazenamento das cargas elétricas

no sistema off-grid, em que posteriormente serão consumidas nos períodos noturnos

ou em dias não ensolarados. As baterias mais recomendadas são as do tipo esta-

cionárias, tipicamente são aplicadas a funções que demandam por longos períodos

de corrente elétrica moderada. Além disso, são projetadas para suportar períodos

maiores de descarga e duram muito mais tempo. Consequentemente, são as mais

adequadas para o uso em sistemas solares fotovoltaicos (SOLARBRASIL, 2019).

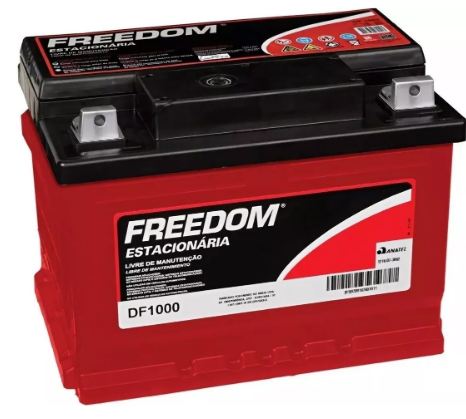
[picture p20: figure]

Figura 3.6: Bateria estacionária.

Especialista

Para execução do projeto é essencial o conhecimento profundo da coisa, neste caso, os

sistemas de geração de energia solar fotovoltaicos. Dessa forma, o projeto vai contar com

a colaboração de um especialista, o professor Dr. Marcelo Gradella Villalva, da FEEC, o

qual nos forneceu o empréstimo de uma placa fotovoltaica e nós apresentou ao pessoal do

Laboratório de Eletrônica de Potência (LEPO) com participação especial dos alunos de

pós-graduação João Lucas e Hugo. Ambos possuem grande conhecimento nos sistemas

de geração solar fotovoltaica e inclusive na medição da tensão e corrente.

Regras de Negócio

A solução de monitoramento da mini usina de energia fotovoltaica deve emitir alertas

sobre possíveis falhas no sistema de geração de energia elétrica de um painel fotovoltaico.

A emissão de alertas pode orientar uma equipe de técnicos sobre a necessidade da realizar

a manutenção do equipamento.

A falha nos painéis fotovoltaicos será identificada por meio da queda na geração de

energia, dessa forma será medido a produção de energia de cada painel. A geração de

energia dos painéis pode variar devido à perda de eficiência do painel, isso pode ocorrer

por diversos fatores, como por exemplo, pela temperatura dos painéis, ação do tempo e

do sol, falhas nos conectores, etc. Pelos dados coletados o sistema deve distinguir se a

queda na produção foi ocasionada por condições ambientais ou por falha no sistema.

A eficiência de um painel solar está relacionada a porcentagem de luz solar que o painel

consegue converter em energia, ou seja um painel cuja eficiência é de 17% converte 17%

da energia da luz do sol que incide sobre ele por m²
, em energia elétrica.

Para calcular a eficiência, em porcentagem, de um painel solar faz-se a divisão potência

(w) pela área do painel e divide o resultado novamente por 10. A Tabela 3.1 apresenta

uma classificação de eficiência dos painéis solares com referência conversão de energia da

luz do sol em energia elétrica (PORTALSOLAR, 2019).

A classificação da eficiência dos painéis solares é realizada em laboratório, seguindo

condições normais de ensino. As condições normais de ensino definem que o painel deve

estar a uma temperatura de 25o C, incidindo sobre ele uma irradiação solar de 1000

Watts m²
e uma massa de ar de 1,5. Ocorre que em temperatura elevadas, como é o

caso do Brasil, os painéis solares perdem eficiência, essa perda de eficiência é conhecida

Eficiência | Porcentagem do total de painéis produzidos | Classificação
> 18 % | ∼10% | Alta eficiência
17 − 17.9 % | ∼ 30% | Acima da média de eficiência
16 − 16.9 % | ∼ 30% | Eficiência padrão
15 − 15.9 % | ∼ 20% | Abaixo da média de eficiência
< 15% | ∼ 10% | Baixa eficiência

Tabela 3.1: Classificação com relação a eficiência com a proporção dos painéis produzidos

como coeficiente de temperatura e é descrita na ficha técnica do equipamento. Alguns

equipamentos podem apresentar até 0,5%/oC, que indica que o painel perde 0,5% de

eficiência a cada grau Celsius acima dos 25oC. É importante observar que a temperatura

considerada é a do painel e não a temperatura do ambiente, assim alguns painéis podem

atingir temperaturas acima de 50oC o que resultaria numa perda de eficiência de 12,5%.

Além da temperatura os painéis solares também perdem em média 3% de eficiência

no primeiro ano de uso e a cada ano subsequente cerca de 0,7% devido ao desgaste do

equipamento e exposição ao sol.

Esses parâmetros de perda de eficiência por temperatura e por tempo de uso devem ser

considerados para emissão de alertas falhas na geração de energia elétrica. Além desses

parâmetros dados históricos do sistema podem ser comparados para comprovar/refutar a

perda de eficiência dos paneis e realizar previsões de geração de energia.

Com base nas informações coletadas também será possível auxiliar na verificação de

viabilidade de expansão do sistema de geração.

Para fins de conscientização ambiental a solução irá apresentar em tempo real a redu-

ção de CO2 lançado na atmosfera e o equivalente ao número de árvores plantadas.

### 3.2.2 Segundo ciclo, Especificações Top-Down

O diagrama a seguir resume a conexão entre os sete níveis do modelo de referência podendo

ser útil tanto para o ciclo das Especificações como para a Implementação. No caso das

especificações, são estabelecidos seis níveis que ligam o negócio (Nível 7) e a coisa (Nível

0), segundo o modelo de referência por um approach top-down.

Neste ciclo, os níveis são discutidos a seguir:

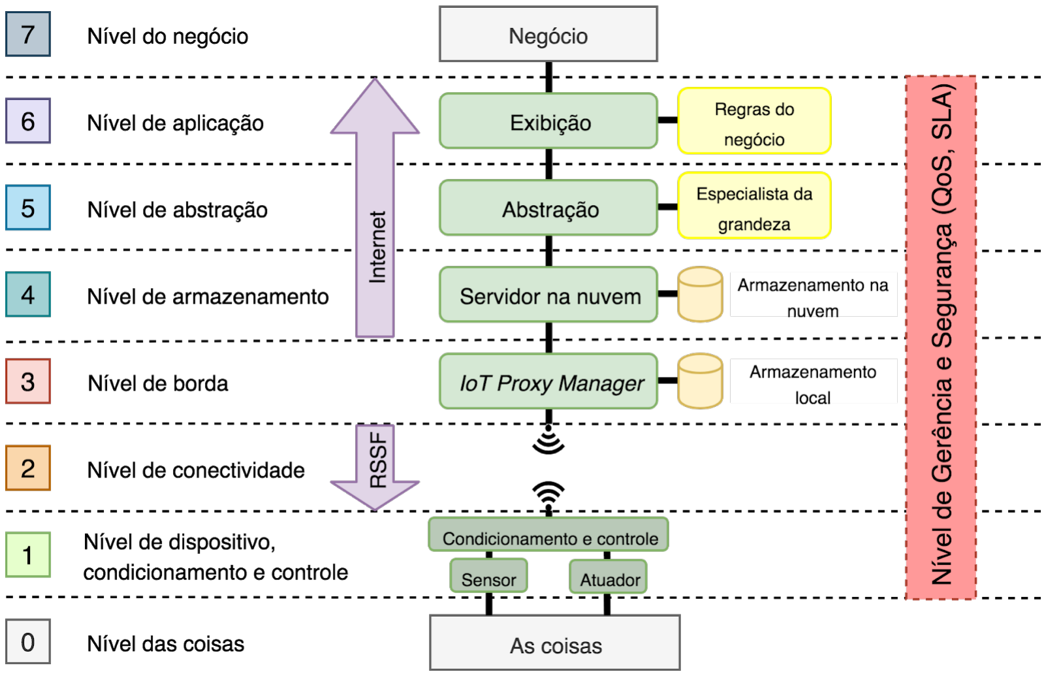
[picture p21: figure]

Figura 3.7: Diagrama de conexão entre os níveis do modelo de referência.

Nível 7 – Negócio

O negócio contemplado nesse projeto foi a geração fotovoltaica construída na Unicamp,

um subprojeto do Campus Sustentável, visando economia de energia. Ao todo será ins-

talado 573 kWp de geração no campus, focaremos na microgeração instalada na FEEC -

Faculdade de Engenharia Elétrica e de Computação, com 97 kWp.

Nível 6 - Exibição

As informações a serem exibidas ao usuário serão os limites de tensão, corrente e tempe-

ratura, mostrados através de gráficos. A quantidade de energia produzida que poderá ser

vista por todos os usuários. Para o gerente da rede serão exibidos os valores de Intensi-

dade do Sinal Recebido (RSSI). No que diz respeito a alarmes, haverão avisos por e-mail

e WhatsApp quando os níveis de tensão e corrente chegarem a valores não condizentes

com a operação.

Nível 5 – Abstração

A abstração foi feita com a ajuda de um especialista, o prof. Dr. Marcelo Gradella

Villalva, da FEEC. A atuação do especialista se deu como responsável por apresentar os

parâmetros da operação, quais são os limites da rede de energia e qual o seu comporta-

mento esperado. Em relação ao tratamento dos dados, serão calculados os valores médio,

máximo e mínimo, além de uma extração estatística. As técnicas para o tratamento dos

dados serão a eliminação de outliers e identificação de tendencias.

Nível 4 – Storage

O armazenamento dos dados será feito localmente e na nuvem. Os dados armazenados

foram tensão, corrente, temperatura, RSSI e potência.

Nível 3 – Borda

O elemento de borda é responsável pela conexão da RSSF à Internet estando presente no

laboratório LE37 e será alimentado por uma fonte de 5V conectada à rede de energia. A

comunicação para a RSSF será feita por um cabo USB. Ethernet ou Wi-Fi para o envio

dos dados para a nuvem.

Nível 2 – Conectividade

O nó sensor ficará junto as placas e a Estação Rádio Base (ERB) estará no laboratório

LE37. A antena da ERB consegue realizar a cobertura do nó sensor, havendo apenas

um enlace entre a ERB e o nó sensor. Há uma segurança física nas placas fotovoltaicas,

então o nó sensor não estará em um local de fácil acesso. Existem poucos obstáculos entre

o nó sensor e a ERB. A antena da ERB está em uma posição privilegiada, no topo do

prédio de laboratórios da FEEC. A transmissão será feita por radiofrequência utilizando

a frequência 915MHz.

Nível 1 – Nó Local Sensor/Atuador

O nó sensor ficará junto às placas na área de micro-geração da FEEC. Haverá apenas um

nó sensor que será alimentado por meio de bateria.

Nível 0 – Coisas

A coisa utilizada no projeto é o painel fotovoltaico, utilizado na micro-geração da FEEC.

### 3.2.3 Terceiro ciclo, Implementação (Bottom-Up)

Neste ciclo é feita a utilização dos níveis mencionados anteriormente. No entanto, agora

com abordagem bottom up. Ou seja, partindo dos níveis de números menores (mais perto

da coisa) até os de números maiores (mais perto do negócio).

Nível 1 – Nó Local Sensor/Atuador

Será utilizado uma placa de desenvolvimento DK107, um divisor de tensão para a medição

da tensão do painel, um sensor medidor de corrente Allegro ACS712 e um sensor de

temperatura. O sensor utilizado para medir a corrente da placa é o ACS712, com um

range de -30A até 30A. Para medir a tensão da placa será utilizado divisor resistivo para

diminuir a tensão, Foi utilizado como referência a dissertação de mestrado “Sistema de

baixo custo para monitoramento da geração de energia solar com conexão para internet

das coisas” do Ricardo Mazza Zago.

Nível 2 – Conectividade

A conectividade será feita através de uma rede de sensores sem fio (RSSF) com módulos

de comunicação BE900 e uma placa de desenvolvimento DK107 no nó sensor. Os módulos

de comunicação possuem o transceptor CC1101 e o microcontrolador ATmega328.

Nível 3 – Borda

O elemento de borda será uma Raspberry Pi 3, e ERB enviando os dados da comunicação

para o computador.

Nível 4 – Storage

Para o armazenamento de dados será utilizando um banco de dados relacional MySQL.

Nível 5 – Abstração

Na primeira etapa do projeto a abstração será realizada com a definição de limites para as

grandezas mensuradas. Os limites são determinados pelo especialista do negócio e pelos

fabricantes dos painéis fotovoltaicos. Se a potência medida estiver abaixo da especificada,

o alerta, então é emitido.

Nível 6 - Exibição

Para exibição dos dados foi desenvolvido um sistema web que possibilita consultar a

tensão, a corrente e a potência dos painéis solares. O sistema também realiza alertas

caso os valores das grandezas medidas não estejam dentro dos limites estabelecidos pelo

especialista do negócio.

## 3.3 Esquemas Elétricos

### 3.3.1 Materiais utilizados

Os materiais que são utilizados neste projeto são listados na Tabela 3.2.

Item | Uni | Quant | Descrição | Unitário | Total
1 | UN | 2 | Módulos de comunicação BE900 | R$ 180,00 R$ 360,00
2 | UN | 1 | UARTsBee | R$ 127,00 R$ 127,00
3 | UN | 2 | Antenas omnidireccional de 2,15 dBi | R$ 29,00 | R$ 58,00
4 | UN | 1 | Placa de desenvolvimento DK 107 | R$ 165,00 R$ 165,00
5 | UN | 1 | Raspberry Pi | R$ 290,00 R$ 290,00
6 | UN | 1 | Sensor Allegro ACS712 | R$ 26,90 | R$ 26,90
7 | UN | 1 | LM35 | R$ 10,90 | R$ 10,90

Tabela 3.2: Nível de ruído e resolução vs. Capacitância de filtragem e resolução de largura

de banda.

### 3.3.2 Descrição dos hardwares utilizados

O projeto do hardware implementado para o sistema de monitoramento solar teve como

base a necessidade de medição de variáveis específicas como, tensão, corrente e tempera-

tura. Dessa forma, foi projetada uma placa, com o auxílio do SATE na FEEC/Unicamp, para a implementação do circuito contendo o nó local sensor/atuador. Na placa estão

contidos dois resistores de precisão com 91 e 10 kΩs, respectivamente, um capacitor de

100 pF e um sensor de corrente Allegro ACS712. A descrição do sensor mencionado está

presente na subseção 3.3.3.

(a) Vista Superior | (b) Vista Inferior

Figura 3.8: Placa projetada para execução do monitoramento com a ajuda do SATE.

Os resistores presentes na placa estão associados de forma a criar um divisor de tensão

que tem por finalidade a medição da tensão gerada pelo painel solar. O objetivo do mesmo

consiste na redução do valor de tensão gerada pelo painel para o valor máximo de 5V, dito

máximo para utilização do Raspberry. A presença do capacitor se justifica como técnica

de redução de ruído, possibilitando medições mais precisas das variáveis.

A conectividade do sistema se deu com a utilização de uma RSSF. Nela, estão con-

tidos o módulo de comunicação BE900, que possui o microcontrolador ATmega328 e o

transceptor CC1101, e uma placa de desenvolvimento DK107, presente no nó sensor.

O BE900 foi escolhido por questões envolvendo o seu sistema de comunicação a rádio

e pela sua grande utilização em RSSF. Pode ser alimentado por tensões de 3, 3V até 5V e

foi implementado em Arduino. A sua faixa de operação é de frequência de 915 MHz para

a transmissão dos dados com uma potência de 10 dBm.

O Atmega328 é um microcontrolador de 8 bits com arquitetura Harvard modificada. É

produzido pela empresa Atmel, considerado na família megaAVR. Em relação a memória,

são 32 kB de memória flash, 1 kB de EEPROM e 2 kB de RAM. Dos 28 pinos, 23 são de

Input/Output, 32 registradores e 3 timers, sendo o timer0 e o timer2 de 8 bits e o timer1 de

16 bits. Possui serial programável USART, uma interface I2C, conversor A/D de 6 canais

e 10 bits, whatchdog timer interno programável com presença de oscilador e cinco modos

de energia por software. Opera entre 1, 8V e 5, 5V, alcançando taxa de transferência

de 1 MIPS (Millions of Instructions per Seconds) por MHz. Devido sua simplicidade,

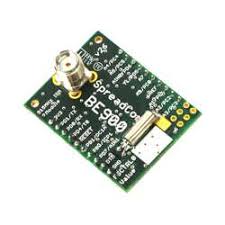
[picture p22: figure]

Figura 3.9: Módulo de comunicação BE900.

baixa potência e ao baixo custo, é normalmente utilizado em projetos autônomos e mais

comumente implementado em Arduino (CAETANO, 2018).

O CC1101 é um transceptor de rádio sub-1GHz projetado para aplicações em redes sem

fio de baixa potência. É produzido para aplicações nas áreas científica, médica e indus-

trial. É integrado com modem de banda base altamente configurável, que suporta vários

formatos de configuração e possui taxa de dados configurável acima de 600 kbps. For-

nece suporte para hardware para manuseamento de pacotes, data buffering, transmissões

em rajada, indicação de qualidade do link e wake-on-radio. Seus principais parâmetros

são configurados via interface SPI e é tipicamente utilizado junto a um microcontrolador

(INSTRUMENTS, 2018).

Como elemento de borda do projeto foi utilizado um computador de plana única

Raspberry Pi 3. Sua escolha para utilização no projeto se deu por questões de custo

benefício. Ele possui um processador com quatro núcleos (Quad Core com 1,2GHz),

memória RAM de 1 GB, quatro portas USB, além de entrada de cartão Micro SD para o

sistema operacional, Raspbian, e a realização da coleta de dados. Por meio de um script

em Python, o sistema operacional constrói o pacote da RSSF e realiza o tratamento dos

dados coletados.

Figura 3.10: Raspberry Pi 3.

### 3.3.3 Descrição dos Sensores

Após realizar uma pesquisa de mercado foi observado que a melhor opção de custo bene-

fício para realizar as medidas da corrente é com o sensor Allegro ACS712, o qual pode ser

visto na figura a seguir.

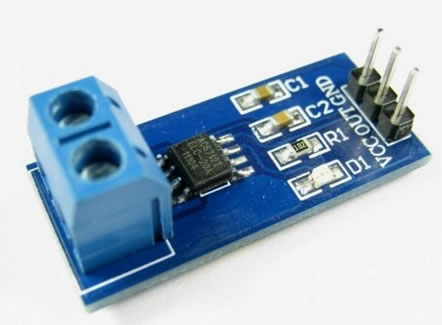
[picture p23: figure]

Figura 3.11: Sensor de corrente Allegro ACS712.

Este sensor é classificado como invasivo, ou seja, é necessário abrir o circuito para fazer

a medição. Além disso, ao adicioná-lo ao circuito provoca uma baixa queda de tensão

durante a medição, devido a sua resistência interna ser de apenas 1, 2 mΩ. Possui fundo

de escala de −30 A até 30 A tanto para corrente contínua como para alternada, com uma

sensibilidade de aproximadamente 0,066 mV/A. A medição ocorre por meio do efeito hall

para detectar o campo magnético gerado pela corrente.

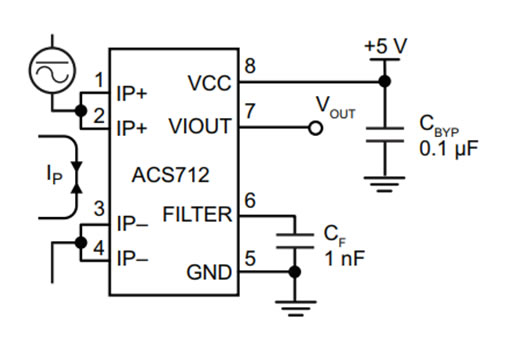
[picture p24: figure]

Figura 3.12: Circuito esquemático do sensor de corrente.

Onde, Vcc, é o pino de alimentação do circuito, em que será utilizado uma bateria para

poder alimentá-lo. Viout é o pino que informa os dados da corrente e tensão medidos GND

é o pino terra, os pinos IP+ e IP- conectam-se em série ao circuito que deverá ser medido.

No site da Allegro, empresa responsável pela fabricação do sensor, há uma página

de FAQ. Perguntaram qual a menor corrente que pode ser medida pelo ACS712, foi

respondido que a sua resolução é determinada pelo nível de ruído, mostrando assim uma

tabela das características de filtros que podem ser aplicadas. Dependendo do valor da

corrente que será necessário medir, é necessário alterar o capacitor utilizado.

Ruido P k − P k (mV) | Resolução Corrente (mA) | Cf (nF) | BW (kHz)
92 | 497 | 0 | 80
46 | 249 | 4.7 | 19.9
26 | 141 | 22 | 4.3
20 | 108 | 47 | 2.0

Tabela 3.3: Nível de ruído e resolução vs. Capacitância de filtragem e resolução de largura

de banda.

A tensão a ser medida será realizada diretamente, mas como a entrada pino de medição

não deve possuir uma tensão maior do que 5V. Então será realizado um divisor de tensão

para abaixar a tensão gerada. Este circuito é ilustrado a figura a seguir. O capacitor tem

o objetivo de reduzir possíveis ruídos na medição.

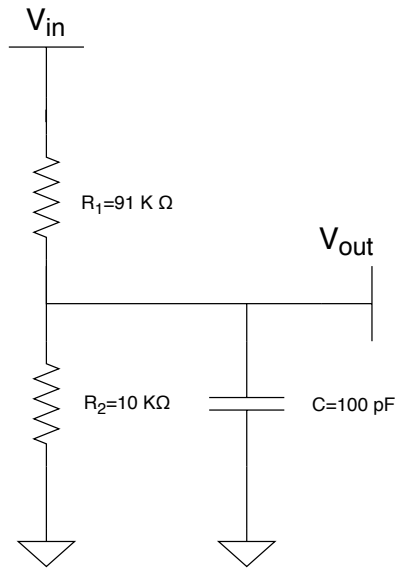
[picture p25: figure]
Vin; Vout

Figura 3.13: Divisor de tensão.

Outra medida a ser informada é a temperatura, pois apesar do aumento na irradiação

solar sobre a placa fotovoltaica fornecer mais energia, o aumento da temperatura da

placa danifica-a. Logo, sensor selecionado para esta medição é o LM35 encapsulado com

proteção contra fatores adversos, como a chuva.


Figura 3.14: LM35 não encapsulado.

Este é um sensor digital, cuja faixa de operação é de 0 a 100oC com boa precisão, é

utilizado em vários projetos de automação residencial/industrial, e de fácil aplicação para

microprocessadores, como PIC, ARM, Arduino e Raspberry Pi, cuja comunicação ocorre

por apenas um pino.

Enfim, o esquema de conexão de todos estes sensores é feita de acordo com a Figura

ACS 712; MPPT; DIvisor de Tensão; Rede/Carga

Figura 3.15: Esquema de conexão dos sensores ao sistema de geração de energia solar

fotovoltaica.

Observe que para a medição adequada, é necessário que o sistema esteja conectado a

um otimizador de potência em MPPT.

Com este esquema, foi projetado uma placa impressa para a unificação de todos os

sensores apresentados na Figura 3.16. Observe a presença dos conectores Screw, que é

o terminal de entrada para conexão com o sistema fotovoltaico, do sensor de Corrente

ACS712, do conector grove para a comunicação com o DK107, e o divisor de tensão. A

placa montada com todos estes componentes está apresentada na Figura 3.17.


Figura 3.16: Esquema do circuito impresso

Figura 3.17: Circuito impresso pronto.

## 3.4 Método de transmissão

### 3.4.1 Rede de Sensores Sem Fio

A comunicação do sistema foi realizada por uma Rede de Sensores Sem Fio (RSSF). Uma

RSSF monitora as condições do ambiente que a cerca, por meio de variados sensores

e transmite esses dados sem a utilização de fios. Sendo usada nas áreas militar, meio-

ambiente, saúde, residencial e industrial (AKYILDIZ; VURAN, 2010). Os Nós Sensores são responsáveis por coletar informações do meio e enviar para a Estação Rádio Base

(ERB). Esse, por sua vez, recebe as informações e está ligado ao gateway, que conecta

a RSSF à Internet, isso pode ser feito através de Ethernet, Wi-Fi ou Universal Serial

Bus (USB). Além dos módulos de comunicação, o bom funcionamento das RSSF tam-

bém se deve às antenas utilizadas. A antena é um condutor que capta um sinal guiado

(comunicação por fio) e o transforma em um sinal não guiado (transmissão pelo ar). As

características de uma antena são determinadas pelo diagrama de irradiação da mesma

(BRANQUINHO, 2014; DÉO; BRANQUINHO, 2017).

### 3.4.2 IoT Proxy Manager

Foi exposto por Oliveira (2016) que a RSSF possui limitações como falta de capacidade

computacional e de “hosts”, necessitando de uma plataforma de gerenciamento no gateway.

Ao avaliar os dados recebidos e a infraestrutura da rede, essa plataforma foi nomeada

Proxy Manager. O Proxy Manager realiza três funções: Coleta e tratamento dos dados,

interface entre os dados e a Internet e a aplicação na Internet, assim nesse trabalho esse

elemento de borda foi denominado IoT Proxy Manager. Oliveira (2016) também propôs

a estrutura como um todo, visto na Figura 3.18.

Figura 3.18: Diagrama em blocos da estrutura da rede.

Os elementos do sistema são: a RSSF; o IoT Proxy Manager, que realiza a conexão à

Internet; e uma plataforma na nuvem, possuindo um banco de dados e a análise estatística dos mesmos. No IoT Proxy Manager, há o Gerente da Rede, responsável por monitorar

e controlar a rede, os parâmetros do sistema são inseridos através dele Stallings (1996).

Também há o Gerente dos Dados que realiza cálculos estatísticos e tratamento dos dados.

Ambas gerências são realizadas por meio de um script Python.

### 3.4.3 Módulos de comunicação e plataforma de desenvolvimento

Para a RSSF foi escolhido o módulo de comunicação BE900 que é considerado Low Power

Wide Area Network (LPWAN) e opera nas frequências não licenciadas, que são reservadas

para o desenvolvimento Industrial, Científico e Médico (Industrial Scientific and Medical,

ISM).

Essa é uma tecnologia nacional e atende as regulamentações da Agência Nacional de

Telecomunicações (ANATEL), o módulo utiliza uma plataforma open-source, tornando

fácil a implementação de novos protocolos de comunicação e diferentes topologias de rede.

Para realizar a programação do Nó Sensor e assim o desenvolvimento da rede, foi utili-

zado a plataforma open-source Radiuino. Essa ferramenta tem como modelo conceitual as

camadas do Protocolo de Controle de Transmissão/Protocolo da Internet (Transmission

Control Protocol/Internet Protocol, TCP/IP), sendo elas a Física, Controle de Acesso ao

Meio (Media Access Control, MAC), Rede, Transporte e Aplicação.

Cada pacote possui 52 bytes, seguindo a seguinte estrutura: 16 bytes para os cabeça-

lhos das camadas Física, Enlace, Rede e Transporte (4 bytes cada uma), 18 bytes para os

conversores analógico para digital (AD0, AD1, AD2, AD3, AD4 e AD5) e 18 bytes para

as entradas ou saídas digitais (IO0, IO1, IO2, IO3, IO4 e IO5).

Nos bytes da camada Física são escritos os dados do “link” do rádio, tal como o

Indicador da Intensidade do Sinal Recebido, (Received Signal Strength Indicator, RSSI)

e o Indicador da Qualidade do “Link” (Link Quality Indicator, LQI). Na camada MAC é

configurado o modo de repouso ou sleep mode, esse modo faz o dispositivo “dormir” entre

transmissões, economizando energia e aumentando a vida útil do mesmo.

A camada de Rede é responsável pelo roteamento dos pacotes e a de Transporte pela

contagem deles. A camada de Transporte também realiza a segurança das informações.

A camada de Aplicação realiza as medidas dos Nós Sensores. Os elementos da rede e suas

camadas estão dispostos na Figura 3.19.


Figura 3.19: Elementos da rede e suas respectivas camadas.

Os firmwares da ERB só possuem as três primeiras camadas, pois não realiza nenhuma

aplicação e não possui informações, isso é feito pelo IoT Proxy Manager que está conectado

à ERB através de um cabo mini USB. O Nó Sensor possui todas as camadas e está se

comunicando pelo ar.

### 3.4.4 Framework

Utilizando o modelo de referência, mostrado anteriormente, é possível desenvolver um

framework, mostrando uma sequência de ações que concretizam a rede. Esse framework

é visto na Figura 3.20.


Figura 3.20: Framework.

O primeiro passo para o desenvolvimento de uma RSSF é definir: quem será o usuário

dessa rede, o que ele deseja monitorar e com qual sensor. Após essa primeira análise

é possível começar a desenvolver a rede, escolhendo os módulos de comunicação e os

aferindo, desenvolvendo os parâmetros da rede e os firmwares que serão utilizados pelos

módulos.

Um survey da área a ser monitorada deve ser realizado, levando em consideração a

distância entres os pontos de medição e a localização dos mesmos. Verificando se há visada

com a ERB, pontos de energia ou incidência solar e até se há a necessidade de alguma

autorização mediante a instalação.


Figura 3.21: Fluxograma

Depois desse estudo, é decidido os tipos das antenas que realizam a melhor cobertura

para cada caso e testes de campo para verificar a comunicação são realizados.

Feito toda esta análise, é preciso deixar a decisão no controle de alguém que esteja

supervisionando toda a RSSF projetada para monitorar os dados da geração solar foto-

voltaica. A Figura 3.21 apresenta a ideia envolvendo toda a RSSF.

Possíveis problemas que podem ocorrer neste sistema em que o supervisor será infor-

mado para a tomada de decisão são destacados a seguir

- Quando a diferença de tensão entre ambas as extremidades das placas cair a zero.

Isto corresponde a um curto circuito, logo a instalação deve ser verificada para o

sistema ser rearranjando.

- Temperatura muito alta dos painéis solares. Neste caso, pode ser ligado um sistema

de resfriamento, visto que o calor reduz o tempo de vida do painel solar.

- Quando a diferença muito grande, não comum e por um longo período de tempo

para um no específico com relação aos seus vizinhos. Neste caso, uma equipe de

analise técnica pode ser chamada para verificar possíveis problemas que estejam

interferindo na geração de energia sobre o nó específico

## 3.5 Software

### 3.5.1 Modelagem dos Dados

O presente sistema foi concebido, a princípio, para monitorar a produção de energia solar

e a eficiência dos painéis fotovoltaicos instalados na Unicamp. No entanto o sistema foi

implementado para atender uma maior variedade de clientes e usuários.

O sistema poderia ser comercializado para revendedores/fabricantes de painéis fotovol-

taico, que agregaria ao seu produto um sistema de monitoramento e suporte ao pós-venda.

O sistema possibilita monitorar as usinas de diversos clientes. Cada cliente pode

possuir uma ou várias usinas solares (instalações), as instalações são compostas por painéis

fotovoltaicos. De cada painel solar são armazenadas as especificações do fornecedor, como

a potência mínima, potência máxima, tensão máxima, eficiência e coeficiente térmico.

Dada as características e a quantidade de painéis fotovoltaico é possível determinar

a potência total das instalações de um cliente. Para cada instalação são armazenados

dois tipos de medição. Uma medição, realizada próximo ao tempo real, que armazena a

medição realizada pelo sensor no momento que ela é recebida pelo elemento de borda, e

uma medição das médias coletadas pelos sensores. Apenas a última medição próxima ao

tempo real é armazenada no banco de dados. No armazenamento das medições por média

é realizada a cada 30 minutos, podendo esse tempo ser reconfigurado.

Durante as medições o elemento de borda com base nas configurações da instalação

verifica se ocorreu uma falha. Atualmente duas categorias de falhas são tratadas pelo

sistema: falta de comunicação entre o elemento de borda e os sensores e a falha na

potência gerada pela usina solar.

Quando a falha na comunicação entre o elemento de borda e os sensores, o algoritmo

do elemento de borda tenta reestabelecer a conexão, caso contrário e registra a ocorrência

da falha. No caso da falha na potência gerada pela usina solar, o sistema simplesmente

registra a falha.

Para notificar o usuário que houve uma falha no sistema ou na usina, o elemento de

borda encaminha e-mail e uma mensagem por WhatsApp para os contados do cliente

armazenados no sistema. A Figura 3.22 apresenta o modelo de entidade e relacionamento

que o sistema utiliza para armazenar as informações.


Figura 3.22: Modelo Entidade e Relacionamento.

### 3.5.2 Funcionalidades do sistema

Para apresentar as funcionalidades do sistema IOT de monitoramento solar é apresentado

na Figura 3.23 o diagrama de casos de uso do sistema. O diagrama de casos de uso é

um dos diagramas da UML – Unified Modeling Language, amplamente utilizado para a

modelagem de sistemas.

No diagrama os atores (bonecos) representam os papeis que um usuário pode de-

sempenhar ao utilizar o sistema. Os casos de uso (elipses) são as funções externamente

observáveis do sistema que podem ser realizadas por um ator. Neste projeto o sistema

possui 3 atores, o cliente, o operador e o ator sistêmico.

O ator cliente (proprietário) monitorar as medições realizadas pelo sistema e verificar

a ocorrências de falhas, seja por falta de conexão ou por falha na produção de energia.

O ator operador executa a maior parte das funcionalidades do sistema. Ele é responsável

por cadastrar os clientes e suas usinas solares. Este ator precisa ter conhecimento sobre

o negócio para configurá-lo e fornecer as especificações corretas dos painéis utilizados em

cada instalação.

O operador também é responsável por monitorar o sistema e tomar as providencias

em caso de falha na geração de energia. Caso o sistema fosse adquirido por um fabricante

ou revendedor de painéis solares as informações sobre falhas poderiam ser utilizadas para

prestar serviços de pós-venda.

O sistema também é considerado um ator neste projeto, pois ele é responsável por

receber as medições realizadas pelos sensores, realizar a análise de falhas e encaminha

mensagens de alertas para os clientes e operadores cadastrados.


Figura 3.23: Diagrama de casos de uso.

### 3.5.3 Atividades do sistema

O sistema IOT de monitoramento solar é composto por 3 subsistemas que realizam ati-

vidades bem definidas. A fim de apresentar as funcionalidades desempenhada por cada

módulo a Figura 3.24 apresenta o diagrama de atividades do sistema. O diagrama de

atividades, assim como o diagrama de casos de uso, pertence a linguagem de modelagem

unificada (UML), esse diagrama tem por objetivo demostrar o comportamento do sistema

e o fluxo de processamento.

O diagrama apresenta 4 guias, sendo que as 3 primeiras representam as atividades

desempenhadas pelo sistema e a última guia representa o usuário do sistema.

A guia sensores é responsável por coletar os dados das usinas solares, após a coleta

dos dados os outliers são removidos utilizando o método estatístico z-score melhorado. O

z-score padrão utiliza a média e o desvio padrão para determinar se um ponto observado

é um outliers, esse método é pouco preciso para pequenas amostras coletadas. O z-score

melhorado utiliza a mediana e o desvio absoluto mediano, dessa forma o z-score melhorado

não sofre a influência dos outliers, sendo mais efetivo na sua remoção.

O elemento de borda realiza a coleta e tratamento dos dados, a interface entre os

dados e a Internet e a aplicação na Internet. Após a coleta e o tratamento, os dados

são disponibilizados para o sistema web, que apresenta as informações aos operadores e

clientes que podem tomar decisões.


Figura 3.24: Diagrama de atividades.

### 3.5.4 Sistema Web

O sistema web é responsável por coletar os dados tratados do elemento de borda e gerar

informações gerenciais para os usuários do sistema. As informações são apresentadas

em formato de dashboard. As dashboards são painéis que mostram métricas e indicadores

importantes para os atores do sistema tomarem decisões a alçarem seus objetivos e metas.

A Figura 3.25 apresenta a primeira versão da dashboard de monitoramento de uma

usina fotovoltaica. Na dashboard é possível obter a quantidade de energia gerada até o

momento, a potência atual e o histórico de geração, o valor em reais referente a energia

produzida e coeficiente de árvores cultivadas, considerando o valor médio de emissão de

CO2.

Figura 3.25: Dashboard do sistema web.

A Figura 3.26 apresenta as mensagens de falhas detectadas pelo sistema. Além das

mensagens de falha exibidas no sistema web notificações por e-mail e por WhatsApp

também são enviadas aos atores do sistema.


Figura 3.26: Alertas de falhas.

A Figura 3.27 apresenta a tela de cadastro de painéis fotovoltaicos de uma usina solar.

Nessa tela é possível realizar as operações CRUD (create, retrieve, update e delete). Os

dados cadastros são utilizados para a identificação de falhas na produção de energia e na

queda de eficiência do sistema.


Figura 3.27: Tela de cadastro de painéis fotovoltaicos.

# Capítulo 4

# Resultados

Com base em toda a abordagem descrita no Capítulo 3, os resultados são obtidos de

forma prática contemplando todo o modelo de referência e destacando as etapas da leitura

adequado dos sensores envolvidos, da transmissão bem sucedida dos dados, do armazena-

mento e da correta exibição pelo software das informações monitoradas.

A Figura 4.1 apresenta a versão final da dashboard discutida no Capítulo anterior, com

os valores atuais do monitoramento dos dados da tensão, corrente, faturamento, número

de árvores plantadas e a potência gerada. As outras funcionalidades que estão presentes

neste ambiente web estão bem detalhadas no Seção 3.5.

Todos os algoritmos utilizados no projeto estão presentes na página do GitHub refe-

rente ao projeto ( https://github.com/softip/monitoramento_solar), incluindo um

vídeo apresentando o funcionamento do sistema.

41

CAPÍTULO 4. RESULTADOS | 42


Figura 4.1: Ambiente com a apresentação dos dados monitorados.

# Capítulo 5

# Conclusão

O presente projeto teve como objetivo o monitoramento de placas fotovoltaicas instaladas

na Unicamp, em virtude do projeto de campus sustentável em conjunto com a CPFL.

É possível concluir que questões envolvendo a eficiência dos painéis e seu tempo de

vida útil condicionado ao ambiente climático ao que estão expostos necessita de maior

tempo de estudo. Assim, seria possível a criação de um histórico para uma análise mais

efetiva deste aspecto.

Em relação à economia de energia, foi concluído que o monitoramento dos painéis pode

contribuir para melhor desempenho do sistema e, consequentemente, maior economia. Tal

fato é corroborado pela presença da tomada de decisão em sistemas IoT possibilita ao

cliente e ao operador estarem cientes do funcionamento dos produtos comercializados.

43

# Referências bibliográficas

AKYILDIZ, I. F.; VURAN, M. C. Wireless Sensor Networks - Vol.4. [S.l.]: JohnWiley

e Sons, 2010. ISBN 9780470036013.

ANEEL. Energia no Brasil e no Mundo., 2019. Disponível em: <http://www2.aneel.

gov.br/arquivos/pdf/atlas_par1_cap2.pdf>. (http://www2.aneel.gov.br/arquivos/pdf/atlas_par1_cap2.pdf)

BRANQUINHO, O. Tecnologias de Redes sem Fio. [S.l.]: Rede Nacional de Ensino e

Pesquisa – RNP, 2014. ISBN 9788563630490.

CAETANO, R. ATmega328, 2018. Disponível em: <https://sites.google.com/site/

ronaldoecaetano/microcontrolador/atmega328>. (https://sites.google.com/site/ronaldoecaetano/microcontrolador/atmega328)

CPFL. CPFL Energia investe R$ 8,1 milhões no Projeto Campus Sustentável da Unicamp,

2018. Disponível em: <https://www.cpfl.com.br/releases/Paginas/cpfl-energia-

investe-81-milhoes-no-projeto-campus-sustentavel-da-unicamp.aspx>. (https://www.cpfl.com.br/releases/Paginas/cpfl-energia-investe-81-milhoes-no-projeto-campus-sustentavel-da-unicamp.aspx)

— Desenvolvimento de um modelo de Campus Sustentável na UNICAMP – Laboratório

vivo de mini geração renovável, mobilidade elétrica, eficiência energética, monitoramento

e gestão do consumo de energia. 2017, 2017. Disponível em: <http://www.ggus.depi.

unicamp.br/wp-content/uploads/2016/03/Chamada-001_Apresenta%5C%C3%5C%A7%

5C%C3%5C%A3oCGU.pdf>. (http://www.ggus.depi.unicamp.br/wp-content/uploads/2016/03/Chamada-001_Apresenta%5C%C3%5C%A7%5C%C3%5C%A3oCGU.pdf)

DÉO, A.; BRANQUINHO, O. Zabbix Aplicado a IoT com Foco no Mercado de Pequenas e

Médias Empresas, 2017. Disponível em: <http://lcv.fee.unicamp.br/images/BTSym-

17/Papers/76634.pdf>. (http://lcv.fee.unicamp.br/images/BTSym-17/Papers/76634.pdf)

GONCALVES, A. R. et al. CENÁRIOS DE EXPANSÃO DA GERAÇÃO SOLAR E EÓ-

LICA NA MATRIZ ELÉTRICA BRASILEIRA. VII Congresso Brasileiro de Energia

Solar, 2018. Disponível em: <https://anaiscbens.emnuvens.com.br/cbens/article/

view/499/499>. (https://anaiscbens.emnuvens.com.br/cbens/article/view/499/499)

44

REFERÊNCIAS BIBLIOGRÁFICAS | 45

INSTRUMENTS, T. Low-Power Sub-1 GHz RF Transceiver, 2018. Disponível em: <http:

//www.mouser.com/ds/2/405/cc1101-82476.pdf/>.

LUCAS. Como Funciona A Energia Solar On-Grid, Off-Grid E Híbrida. ENERGIA

SOLAR INSTALADOR SOLAR DE ALTA PERFORMANCE, 2019. Disponível

em: <https://cursopainelsolar.com/como-funciona-a-energia-solar-on-grid-

off-grid-e-hibrida/>. (https://cursopainelsolar.com/como-funciona-a-energia-solar-on-grid-off-grid-e-hibrida/)

MÜLLER, N. Sustentabilidade Ambiental na Geração de Energia Fotovoltaica. SOLAR-

VOLT, 2019. Disponível em: <https : / / www . solarvoltenergia . com . br / blog /

sustentabilidade-ambiental/>. (https://www.solarvoltenergia.com.br/blog/sustentabilidade-ambiental/)

OLIVEIRA, R. Proposta de um Proxy Manager Para Internet das Coisas. 2016.

Dissertação – Pontifícia Universidade Católica de Campinas.

PEREIRA, R. O que é Geração Distribuída – GD. Portal Solar, 2019. Disponível em:

<https://www.portalsolar.com.br/o-que-e-geracao-distribuida.html>.

PORTALSOLAR. Tudo sobre a Eficiência do Painel Solar, 2019. Disponível em: <https:

//www.portalsolar.com.br/tudo-sobre-a-eficiencia-do-painel-solar.html>.

SOLARBRASIL. Como escolher a bateria para um sistema de energia fotovoltaica Off-

grid? Solar Brasil Tecnologia & Energia Fotovoltaica Ltda, 2019.

STALLINGS, W. SNMP, SNMPv2, and RMON: Practical Network Manage-

ment. [S.l.]: Addison Wesley Longman Publishing Co., 1996. ISBN 0201634791.

VILLALVA, M.; GAZOLI, J. ENERGIA SOLAR FOTOVOLTAICA: CONCEI-

TOS E APLICAÇOES. [S.l.]: ERICA, 2015. ISBN 9788536504162. Disponível em:

<https://books.google.com.br/books?id=etO2NAEACAAJ>.

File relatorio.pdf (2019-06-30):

Universidade Estadual de Campinas Departamento de Engenharia Elétrica e de Computação

## IE309 - Internet Das Coisas: Fundamentos e Oficina Monitoramento Solar

Dimas Augusto Mendes Lemes | 163660
Eloisa A. N. Matthiesen | 208929
Ivan Paulino Pereira | 262125
Rafael Augusto Pedriali | 190742

### Campinas Junho de 2019

# Lista de Figuras

1.1 Mapa de irradiação solar no Brasil (GONCALVES et al., 2018) | | 3
1.2 Exemplo de geração solar distribuída (PEREIRA, 2019) | | 3
1.3 Exemplo de uma usina solar fotovoltaica | | 4
1.4 No lado esquerdo a matriz energética brasileira instalada atualmente e do
lado direito a previsão de expansão para o ano de 2030 | | 5
3.1 Curva de atuação do painel fotovoltaico | | 9
3.2 Diagrama dos três ciclos | 10
3.3 Conjunto de painéis solares | 12
3.4 Inversor de frequência | 13
3.5 Controlador de carga | 14
3.6 Bateria estacionária | 14
3.7 Diagrama de conexão entre os níveis do modelo de referência | 17
3.8 Placa projetada para execução do monitoramento com a ajuda do SATE. . 21
3.9 Módulo de comunicação BE900 | 22
3.10 Raspberry Pi 3 | 23
3.11 Sensor de corrente Allegro ACS712 | 23
3.12 Circuito esquemático do sensor de corrente | 24
3.13 Divisor de tensão | 25
3.14 LM35 não encapsulado | 25
3.15 Esquema de conexão dos sensores ao sistema de geração de energia solar
fotovoltaica | 26
3.16 Esquema do circuito impresso | 27
3.17 Circuito impresso pronto | 27
3.18 Diagrama em blocos da estrutura da rede | 28
3.19 Elementos da rede e suas respectivas camadas | 30
3.20 Framework | 31
3.21 Fluxograma | 32
3.22 Modelo Entidade e Relacionamento | 34
3.23 Diagrama de casos de uso | 35
3.24 Diagrama de atividades | 37
3.25 Dashboard do sistema web | 38
3.26 Alertas de falhas | 39
3.27 Tela de cadastro de painéis fotovoltaicos | 40
4.1 Ambiente com a apresentação dos dados monitorados | 42

# Lista de Tabelas

1.1 Expansão da matriz energética brasileira | 5

3.1 Classificação com relação a eficiência com a proporção dos painéis produzidos 16 3.2 Nível de ruído e resolução vs. Capacitância de filtragem e resolução de
largura de banda | 20
3.3 Nível de ruído e resolução vs. Capacitância de filtragem e resolução de
largura de banda | 24

# Sumário

1 Introdução | 1
2 Objetivo | 6
3 Desenvolvimento | 7
4 Resultados | 41
5 Conclusão | 43
Referências bibliográficas | 44

# Capítulo 1

# Introdução

Diante das novas formas de se usarem os dispositivos eletrônicos, novas tecnologias foram

sendo desenvolvidas e adaptadas para as novas funcionalidades. A busca por maiores taxas

de transmissão de dados, visando formas de conexão que minimizem custos de projeto,

que diminuam a necessidade de alta potência na transmissão e aumentem as áreas de

cobertura sendo confiáveis vêm produzindo resultados nos meios industrial e acadêmico.

Estas tecnologias estão relacionadas ao conceito de Internet das Coisas.

A Internet das Coisas, representada pela sigla IoT (Internet of Things), é definida

de acordo com a União Internacional das Telecomunicações como uma infraestrutura

global que habilita serviços avançados por meio da interconexão entre coisas, ditas físicas

ou virtuais, com base nas tecnologias de informação e comunicação. Ou seja, a ideia é

conectar coisas, objetos do dia-a-dia, dotando-os de capacidade de processar dados. Dessa

forma, uma solução em IoT deve atender a três pré-requisitos. São eles: Reconhecimento

de dados, Conexão a uma rede e a Capacidade de processar os dados sem que haja

interferência humana.

A aplicação de IoT pode trazer benefícios aos cidadãos, à gestão pública, como questões

envolvendo segurança, transporte e eficiência energética, pois permite trazer ao usuário

um poder de decisão sobre o ambiente abordado com muito mais agilidade e facilidade.

Neste projeto a aplicação IoT abordada é voltada sobre sistemas de geração de energia

solar fotovoltaica.

A energia solar fotovoltaica é uma das mais limpas formas de geração de energia

existentes no mundo, a luz do sol é captada por meio de painéis solares que tem por

finalidade realizar a conversão da energia luminosa em energia elétrica. Nesse processo é

1

CAPÍTULO 1. INTRODUÇÃO | 2

possível criar uma rede IoT em que os painéis solares estejam conectados a dispositivos

de comunicação que traduzam, por exemplo, ao consumidor a capacidade de geração de

energia elétrica do sistema, buscando minimizar custos e identificar problemas na geração

da energia.

## 1.1 Matriz energética brasileira

Atualmente a maior fonte de energia elétrica do sistema elétrico brasileiro é sistema hidro-

elétrico, e apresenta-se de forma predominante, em seguida vem as termelétricas, dando

sequencia às energias renováveis como a eólica, solar e biomassa. Embora a energia solar

tenha uma proporção muito pequena de geração sobre o sistema elétrico nacional, ela

possui uma grande previsão de expansão, proporcionado pelo grande potencial de energia

solar incidente no território brasileiro, e pela evolução da tecnologia fotovoltaica tanto

em grandes centrais geradoras fotovoltaicas, quanto na geração distribuída. A Figura 1.1

apresenta o mapa de irradiação solar direta no Brasil, note que este país possui grande

potencial de energia solar (GONCALVES et al., 2018).

A geração solar distribuída ocorre pela geração própria da energia dos consumidores

e que também estão conectados à rede elétrica, além disso, ela é responsável por grande

parte da expansão da energia solar mundial. No Brasil foi instituída em 2012, através

da resolução 482 da ANEEL. Ela permite que consumidores de energia possam gerar a

própria energia através de fontes renováveis e transferir a energia excedente à rede das

concessionárias de distribuição. Isto é, sistema de compensação, conhecido como Net

Metering, ou medição líquida. Quando a geração da energia for maior do que o consumo,

o excedente será injetado na rede de distribuição, gerando créditos energéticos. Deste

modo, quando não há geração, ou quando a energia gerada não for suficiente para suprir

todo o consumo, a energia será fornecida normalmente pela concessionária. Ao final

do mês, o valor a ser pago corresponde à diferença da geração e do consumo. Caso o

saldo da geração seja positivo, os créditos energéticos podem ser utilizados nos 60 meses

subsequentes. Esses créditos também são usados para compensar a fatura de energia

em outros pontos dentro da área de concessão de uma mesma distribuidora (PEREIRA,

2019). A Figura 1.2 apresenta um ótimo exemplo da geração solar distribuída.


CAPÍTULO 1. INTRODUÇÃO | 3

Figura 1.1: Mapa de irradiação solar no Brasil (GONCALVES et al., 2018)

Figura 1.2: Exemplo de geração solar distribuída (PEREIRA, 2019).

A geração centralizada de energia ocorre por meio das usinas solares, e contam com

três características principais:

CAPÍTULO 1. INTRODUÇÃO | 4
- Gerar energia para o mercado livre
- Gerar energia para o mercado cativo, por meio da participação em leilões de energia
- Autogerar energia para grandes consumidores.

A geração centralizada tem sua produção do sistema energético aplicado em um am-

biente particular, sem terceiros ou intermediários permitindo serem empregadas como for

desejado.

Sendo uma das finalidades da geração centralizada o leilão da energia produzida, é

necessária a execução do processo para a realização dos leilões. Que vão desde a inscrição e

habilitação até a finalização do acordo. As usinas solares diferente da geração centralizada

não demanda a execução de leilão para sua distribuição. A sistema de geração de energia

solar em construção da UNICAMP é um exemplo (CPFL, 2017).


Figura 1.3: Exemplo de uma usina solar fotovoltaica.

A previsão de expansão da geração elétrica no Brasil para o ano de 2030 está apresen-

tado na Tabela 1.1. Observe como a geração solar centralizada e distribuída possuem o

maior percentual de crescimento comparado às outras fontes de geração de energia. Outro

gráfico muito interessante está apresentado na Figura 1.4, onde mostra a matriz energé-

CAPÍTULO 1. INTRODUÇÃO | 5
Fonte | 2014 (TWh) | 2030 (TWh) | Participação em 2030 (%) | Incremento (TWh) | Potência Adicional (GWp) | Crescimento (%)
Hidráulica Eólica Solar-Cent. Solar-Dist. Biomassa Outras | 407 697 61 % 290 66 64 % 12 105 9 % 93 26.5 108 % 0 26 2 % 26 14.8 493 % 0 9 1 % 9 5.1 6321 % 41 134 12 % 93 4.2 28 % 164 180 15 % 16 -
Total | 624 1151 527

Tabela 1.1: Expansão da matriz energética brasileira.


Figura 1.4: No lado esquerdo a matriz energética brasileira instalada atualmente e do lado direito a previsão de expansão para o ano de 2030.

tica atual e em construção. Note como as fontes renováveis eólica e solar apresentam um

crescimento expressivo da matriz energética brasileira (GONCALVES et al., 2018).

# Capítulo 2

# Objetivo

O objetivo deste trabalho é desenvolver uma Rede de Sensores Sem Fio (RSSF) para dis-

positivos capazes de monitorar dados de painéis solares. Os dados coletados são corrente,

tensão e temperatura do painel, os quais são transmitidos pelo ambiente sem fio para um

banco de dados sendo possível ter o completo gerenciamento dos dados coletados em um

ambiente online. O banco de dados projetado é capaz de monitorar diversos dispositi-

vos de medição ao mesmo tempo, independente das marcas e modelos dos equipamentos

utilizados nos sistemas de geração fotovoltaica.

6

# Capítulo 3

# Desenvolvimento

A dependência da energia elétrica na sociedade atual é uma necessidade em que geralmente

é suprida pelos sistemas elétricos, no entanto, alguns lugares não possuem acesso ao

sistema devido sua dificuldade de acesso como em áreas rurais remotas e em pequenas

comunidades afastadas onde custo de se conectar à rede seria elevado. Dessa forma, o

fornecimento de energia para estas comunidades pode ser realizada com outras formas

mais viáveis, como é o caso da energia solar fotovoltaica. Além deste aspecto, a energia

solar tem ganhado espaço mundialmente por ter uma geração limpa, inovadora, com

fácil implementação e inclusive pela redução do valor de mercado, tornando-se quase que

popular e com um ótimo custo-benefício.

O desenvolvimento da tecnologia de painéis solares está evoluindo continuamente e

apresentando um elevado potencial de venda para empresas com elevado gasto energé-

tico, para pessoas comuns que queiram realizar economia em suas conta de luz e para

comunidades isoladas. Então este trabalho busca complementar o acesso a informação do

proprietário sobre seu sistema de geração de energia fotovoltaica independente de sua loca-

lização monitorados por uma rede de sensores sem fio. Esta rede notificará ao proprietário

identificação sobre possíveis falhas do sistema.

## 3.1 Sistema de geração de energia solar fotovoltaica

Atualmente existem dois sistemas distintos de geração de energia solar fotovoltaica, o

on-grid e o off-grid, discutidos brevemente a seguir.

7

CAPÍTULO 3. DESENVOLVIMENTO | 8

Sistema off-grid ou isolados, como o nome informa, é um sistema fotovoltaico separado

de qualquer outro sistema de distribuição. A energia que é produzida pelos módulos

fotovoltaicos é basicamente armazenada em um conjunto de baterias, a principal vantagem

é a facilidade de implementação, não sendo necessário ter autorização da companhia

elétrica para implementar.

Sistema on-grid ou sistema fotovoltaico de microgeração distribuída é um sistema

conectado à rede de distribuição de energia, portanto, pode ser considerada como uma

pequena parte do grande sistema de geração integrado. Do ponto de vista econômico, este

sistema não precisa ser conectado à um conjunto de baterias trazendo uma grande eco-

nomia ao projeto, basta apenas conectar o arranjo de painéis a um inversor de frequência

e em seguida levar a energia para a rede elétrica (VILLALVA; GAZOLI, 2015).

Curva de atuação do painel

Os painéis solares têm a capacidade de fornecer uma potencia máxima. Seu valor é

definido em projeto. No entanto ao conectar uma placa à carga, por exemplo de 60 W,

dificilmente o painel estará fornecendo a potência de 60 W. Para que o painel entregue a

máxima potência fornecida pelo fabricante, é necessário que o painel esteja atuando em

um ponto específico, isto é, o MPPT (Maximum Power Point Tracker ) ou Rastreador de

Máxima Potencia do Painel. A curva de atuação em I × V e P × V de uma placa solar

fotovoltaica é esboçado na Figura 3.1 e os pontos definidos no gráfico correspondem a:

- Is/c: Corrente de curto-circuito, é a corrente máxima que o módulo oferece.
- Vo/c: Tensão de circuito aberto, é a tensão máxima oferecida pelo módulo.
- Impp: Corrente de máxima potência, é o ponto de operação de máxima corrente de

operação do módulo.

- Vmpp: Tensão de máxima potência, é a tensão máxima potência apresentada durante

a operação do módulo.

Figura 3.1: Curva de atuação do painel fotovoltaico.

Neste gráfico a curva em azul corresponde aos possíveis valores de atuação do painel

fotovoltaico, e a curva em vermelho é seu correspondente em potência. Para que o painel

atue sobre o MPPT é necessário adicionar ao sistema otimizadores de potência, que são

projetados especificamente para forçarem a os painéis a atuarem sobre estes pontos. Os

otimizadores estão presentes em alguns equipamentos específicos para sistemas de geração

de energia solar, como o inversor de frequência e o controlador de carga (VILLALVA;

GAZOLI, 2015).

Cálculo de árvores cultivadas

O número de árvores cultivadas pode parecer algo um pouco abstrato e intangível, mas é

uma métrica que ajuda a compreender os benefícios ecológicos de um projeto de geração

de energia solar fotovoltaica, a qual está relacionada às energias sustentáveis. Diversas

fontes de energia estão ligadas a queima de combustíveis fósseis, como carvão, petróleo,

gás natural. Dessa forma, o aumento da quantidade de sistemas de geração de ener-

gia solar reduz indiretamente a necessidade das energias produzidas a partir da queima

combustíveis fósseis.

O calculo equivalente ao número de árvores cultivadas é obtido diretamente a partir

da energia elétrica gerada sobre um período de tempo multiplicado pelo coeficiente de árvores cultivadas (5, 04 × 10⁻⁴ árvores/KWh) considerando o fator de emissão médio de

CO2 em 0.1258KgCO2/KWh (MÜLLER, 2019).

## 3.2 Metodologia dos três ciclos

Esta seção descreve detalhadamente a metodologia dos três ciclos (Negócio, Especificação,

Implementação) em um sequência lógica da estrutura do projeto para a implementação

do IoT sobre o cenário proposto.

Negócio; Especificação; Implementação

Figura 3.2: Diagrama dos três ciclos

### 3.2.1 Primeiro ciclo, Negócio

O Negócio

A energia elétrica é indispensável para o desenvolvimento da humanidade, para geração

de bens e serviços e para conforto e segurança da sociedade. De acordo com a ANEEL, o

consumo de energia é dos principais indicadores do desenvolvimento econômico e do nível

de qualidade de vida de qualquer sociedade (ANEEL, 2019).

De acordo com levantamentos realizados pelo Ministério da Educação os gastos com

energia elétrica nas instituições de ensino superior publicas somam cerca de 500 milhões de

reais. Na Universidade Estadual de Campinas - UNICAMP, o consumo de energia elétrica

é cerca de 25 milhões de reais por ano e corresponde a 25% do custeio da universidade

(CPFL, 2018).

Tendo em vista que o gasto com energia elétrica é elevado nas instituições de ensino

superior e que ele compromete cerca 25% do orçamento de custeio da UNICAMP, a

UNICAMP em parceria com a CPFL elaborou o projeto campus sustentável, que faz

parte de um esforço proposto pela ANEEL para reduzir o consumo de energia elétrica nas

universidades públicas.

No que tange ao subprojeto 2 – Mini geração fotovoltaica, será instalado 534 kWp de

geração fotovoltaica, distribuída em 13 locais dentro do campus da UNICAMP, nos seguin-

tes locais: estacionamento GMU, BCCL, CB, Cepetro, IG, ADM, IC, FEC, IFGW, IQ,

FEM, FEA e FEEC. Para realização deste projeto será investido o valor de 3.173.055,20

(três milhões, cento e setenta e três mil, cinquenta e cinco reais e vinte centavos). Espera-

se que esse projeto contribua com a redução de 1.3% de energia consumida atualmente,

ou seja R$ 325.000,00 (trezentos e vinte e cinco mil reais) por ano (CPFL, 2017). Consi-

derando apenas o valor investido e o valor da energia gerada, o investimento será quitado

em 9.7 anos.

Os fabricantes de painéis fotovoltaicos geralmente fornecem garantia de 25 anos para

o produto. No entanto, dada a ação do tempo eles geralmente perdem a capacidade de

geração de energia. Tal capacidade também é influenciada pela temperatura do painel,

bem como pelos períodos de exposição a luz ao longo dos anos. Além da perda de

capacidade natural dos painéis é possível que ocorra problemas nos terminais de contato

por causas das chuvas e outras intempéries que reduzem a produção de energia elétrica.

Considerando que os gastos de energia elétrica comprometem cerca de 25% do orçamento

de custeio da UNICAMP, que a geração de energia fotovoltaica apresenta-se como uma

alternativa para a redução dos gastos com energia e que o investimento na mini usina

representa um valor considerável em relação a energia produzida, este trabalho pretende

produzir um solução em IoT para monitorar a geração de energia e auxiliar na redução

dos gastos com energia.

A solução irá possibilitar monitorar a energia gerada por cada painel solar, ou con-

junto de painéis, e determinar se existe alguma queda anormal na produção de energia,

representando uma falha com o painel. A identificação da falha precocemente irá auxiliar

na manutenção da produção de energia, bem como irá reduzir os custos de manutenção,

tendo em vista que a solução irá identificar o local exato do problema.

A solução também possibilitará ao longo dos anos estimar, com base na produção de

energia passada, a viabilidade da implantação de novos parques de geração fotovoltaica.

A coisa

Neste projeto a definição das coisas será um sistema de geração de energia solar fotovol-

taica, o qual é composto por painéis solares, inversor de frequência, controlador de carga

e bateria. Com estes equipamentos é possível realizar um monitoramento bem adequado

da tensão e da corrente gerada pelo sistema. Com os dados sendo monitorados, é possível

ter acesso a informação de cada um dos elementos da rede. Com estas informações será

possível identificar com mais facilidade e agilidade possíveis falhas localizadas em suas

posições específicas da rede IoT. Os equipamentos referenciados são detalhados a seguir.

- Painel solar: Os painéis solares são construído por várias células de silício ou fotovol-

taica, as quais geram eletricidade a partir da irradiação solar, na forma de corrente

contínua (DC).

As células fotovoltaicas estão ligadas entre si dentro de cada painel solar e conectadas

a painéis adjacentes usando cabos, semelhante ao da Figura 3.3.


Figura 3.3: Conjunto de painéis solares.

Obs: O calor não produz energia, é a irradiação solar. Pelo contrário, o calor danifica

os painéis, fazendo-os perder eficiência com o passar do tempo.

A energia gerada depende das condições climáticas, em um dia nublado/chuvoso, a

quantidade de energia produzida será menor do que dias ensolarados. A quantidade

de energia luminosa é conhecida como irradiação solar e geralmente é calculada ao

longo do dia usando o termo Horas do Sol no Pico (PSH). O para a localização e

tendo em conta a orientação e ângulo de inclinação dos painéis solares (LUCAS,

2019).

- Inversor de frequência: Os painéis solares geram energia de tensão contínua que

precisa ser convertida em tensão alternada para uso em geral, esta conversão é

realizada pelo inversor de frequência. O sistema pode ser projetado utilizando um

microinversor, cujas especificações de atuação não permitem ligar um grande número

de painéis solares, já os inversores de string permitem ligar vários painéis solares.

Outra característica importante dos inversores é que eles também atuam como oti-

mizadores de potência, em que monitoram e controlam a atuação dos painéis para

garantir que cada painel esteja operando com a máxima eficiência sob todas as

condições (LUCAS, 2019).

Figura 3.4: Inversor de frequência.

- Controlador de carga: Os controladores de carga ficam entre os painéis e as baterias e

são utilizados para controlar a voltagem de entrada nelas a fim de evitar sobrecargas

ou descargas excessivas, otimizar a potência gerada pelos painéis e prolongar a sua

vida útil. Os painéis solares produzem energia proporcional a irradiação de luz

solar, porém as baterias não suportam tal variação. Para solucionar este problema e também para aprimorar o carregamento das baterias, são utilizados os controladores

de carga (VILLALVA; GAZOLI, 2015).


Figura 3.5: Controlador de carga.

- bateria: As baterias são responsáveis por todo o armazenamento das cargas elétricas

no sistema off-grid, em que posteriormente serão consumidas nos períodos noturnos

ou em dias não ensolarados. As baterias mais recomendadas são as do tipo esta-

cionárias, tipicamente são aplicadas a funções que demandam por longos períodos

de corrente elétrica moderada. Além disso, são projetadas para suportar períodos

maiores de descarga e duram muito mais tempo. Consequentemente, são as mais

adequadas para o uso em sistemas solares fotovoltaicos (SOLARBRASIL, 2019).


Figura 3.6: Bateria estacionária.

Especialista

Para execução do projeto é essencial o conhecimento profundo da coisa, neste caso, os

sistemas de geração de energia solar fotovoltaicos. Dessa forma, o projeto vai contar com

a colaboração de um especialista, o professor Dr. Marcelo Gradella Villalva, da FEEC, o

qual nos forneceu o empréstimo de uma placa fotovoltaica e nós apresentou ao pessoal do

Laboratório de Eletrônica de Potência (LEPO) com participação especial dos alunos de

pós-graduação João Lucas e Hugo. Ambos possuem grande conhecimento nos sistemas

de geração solar fotovoltaica e inclusive na medição da tensão e corrente.

Regras de Negócio

A solução de monitoramento da mini usina de energia fotovoltaica deve emitir alertas

sobre possíveis falhas no sistema de geração de energia elétrica de um painel fotovoltaico.

A emissão de alertas pode orientar uma equipe de técnicos sobre a necessidade da realizar

a manutenção do equipamento.

A falha nos painéis fotovoltaicos será identificada por meio da queda na geração de

energia, dessa forma será medido a produção de energia de cada painel. A geração de

energia dos painéis pode variar devido à perda de eficiência do painel, isso pode ocorrer

por diversos fatores, como por exemplo, pela temperatura dos painéis, ação do tempo e

do sol, falhas nos conectores, etc. Pelos dados coletados o sistema deve distinguir se a

queda na produção foi ocasionada por condições ambientais ou por falha no sistema.

A eficiência de um painel solar está relacionada a porcentagem de luz solar que o painel

consegue converter em energia, ou seja um painel cuja eficiência é de 17% converte 17%

da energia da luz do sol que incide sobre ele por m²
, em energia elétrica.

Para calcular a eficiência, em porcentagem, de um painel solar faz-se a divisão potência

(w) pela área do painel e divide o resultado novamente por 10. A Tabela 3.1 apresenta

uma classificação de eficiência dos painéis solares com referência conversão de energia da

luz do sol em energia elétrica (PORTALSOLAR, 2019).

A classificação da eficiência dos painéis solares é realizada em laboratório, seguindo

condições normais de ensino. As condições normais de ensino definem que o painel deve

estar a uma temperatura de 25o C, incidindo sobre ele uma irradiação solar de 1000

Watts m²
e uma massa de ar de 1,5. Ocorre que em temperatura elevadas, como é o

caso do Brasil, os painéis solares perdem eficiência, essa perda de eficiência é conhecida

Eficiência | Porcentagem do total de painéis produzidos | Classificação
> 18 % | ∼10% | Alta eficiência
17 − 17.9 % | ∼ 30% | Acima da média de eficiência
16 − 16.9 % | ∼ 30% | Eficiência padrão
15 − 15.9 % | ∼ 20% | Abaixo da média de eficiência
< 15% | ∼ 10% | Baixa eficiência

Tabela 3.1: Classificação com relação a eficiência com a proporção dos painéis produzidos

como coeficiente de temperatura e é descrita na ficha técnica do equipamento. Alguns

equipamentos podem apresentar até 0,5%/oC, que indica que o painel perde 0,5% de

eficiência a cada grau Celsius acima dos 25oC. É importante observar que a temperatura

considerada é a do painel e não a temperatura do ambiente, assim alguns painéis podem

atingir temperaturas acima de 50oC o que resultaria numa perda de eficiência de 12,5%.

Além da temperatura os painéis solares também perdem em média 3% de eficiência

no primeiro ano de uso e a cada ano subsequente cerca de 0,7% devido ao desgaste do

equipamento e exposição ao sol.

Esses parâmetros de perda de eficiência por temperatura e por tempo de uso devem ser

considerados para emissão de alertas falhas na geração de energia elétrica. Além desses

parâmetros dados históricos do sistema podem ser comparados para comprovar/refutar a

perda de eficiência dos paneis e realizar previsões de geração de energia.

Com base nas informações coletadas também será possível auxiliar na verificação de

viabilidade de expansão do sistema de geração.

Para fins de conscientização ambiental a solução irá apresentar em tempo real a redu-

ção de CO2 lançado na atmosfera e o equivalente ao número de arvores plantadas.

### 3.2.2 Segundo ciclo, Especificações Top-Down

O diagrama a seguir resume a conexão entre os sete níveis do modelo de referência podendo

ser útil tanto para o ciclo das Especificações como para a Implementação. No caso das

especificações, são estabelecidos seis níveis que ligam o negócio (Nível 7) e a coisa (Nível

0), segundo o modelo de referência por um approach top-down.

Neste ciclo, os níveis são discutidos a seguir:


Figura 3.7: Diagrama de conexão entre os níveis do modelo de referência.

Nível 7 – Negócio

O negócio contemplado nesse projeto foi a geração fotovoltaica construída na Unicamp,

um subprojeto do Campus Sustentável, visando economia de energia. Ao todo será ins-

talado 573 kWp de geração no campus, focaremos na microgeração instalada na FEEC -

Faculdade de Engenharia Elétrica e de Computação, com 97 kWp.

Nível 6 - Exibição

As informações a serem exibidas ao usuário serão os limites de tensão, corrente e tempe-

ratura, mostrados através de gráficos. A quantidade de energia produzida que poderá ser

vista por todos os usuários. Para o gerente da rede serão exibidos os valores de Intensi-

dade do Sinal Recebido (RSSI). No que diz respeito a alarmes, haverão avisos po e-mail e

WhatsApp quando os níveis de tensão e corrente chegarem a valores não condizentes com

a operação.

Nível 5 – Abstração

A abstração foi feita com a ajuda de um especialista, o prof. Dr. Marcelo Gradella

Villalva, da FEEC. A atuação do especialista se deu como responsável por apresentar os

parâmetros da operação, quais são os limites da rede de energia e qual o seu comporta-

mento esperado. Em relação ao tratamento dos dados, serão calculados os valores médio,

máximo e mínimo, além de uma extração estatística. As técnicas para o tratamento dos

dados serão a eliminação de outliers e identificação de tendencias.

Nível 4 – Storage

O armazenamento dos dados será feito localmente e na nuvem. Os dados armazenados

foram tensão, corrente, temperatura, RSSI e potência.

Nível 3 – Borda

O elemento de borda é responsável pela conexão da RSSF à Internet estando presente no

laboratório LE37 e será alimentado por uma fonte de 5V conectada à rede de energia. A

comunicação para a RSSF será feita por um cabo USB. Ethernet ou Wi-Fi para o envio

dos dados para a nuvem.

Nível 2 – Conectividade

O nó sensor ficará junto as placas e a Estação Rádio Base (ERB) estará no laboratório

LE37. A antena da ERB consegue realizar a cobertura do nó sensor, havendo apenas

um enlace entre a ERB e o nó sensor. Há uma segurança física nas placas fotovoltaicas,

então o nó sensor não estará em um local de fácil acesso. Existem poucos obstáculos entre

o nó sensor e a ERB. A antena da ERB está em uma posição privilegiada, no topo do

prédio de laboratórios da FEEC. A transmissão será feita por radiofrequência utilizando

a frequência 915MHz.

Nível 1 – Nó Local Sensor/Atuador

O nó sensor ficará junto às placas na área de micro-geração da FEEC. Haverá apenas um

nó sensor que será alimentado por meio de bateria.

Nível 0 – Coisas

A coisa utilizada no projeto é o painel fotovoltaico, utilizado na micro-geração da FEEC.

### 3.2.3 Terceiro ciclo, Implementação (Bottom-Up)

Neste ciclo é feita a utilização dos níveis mencionados anteriormente. No entanto, agora

com abordagem bottom up. Ou seja, partindo dos níveis de números menores (mais perto

da coisa) até os de números maiores (mais perto do negócio).

Nível 1 – Nó Local Sensor/Atuador

Será utilizado uma placa de desenvolvimento DK107, um divisor de tensão para a medição

da tensão do painel, um sensor medidor de corrente Allegro ACS712 e um sensor de

temperatura. O sensor utilizado para medir a corrente da placa é o ACS712, com um

range de -30A até 30A. Para medir a tensão da placa será utilizado divisor resistivo para

diminuir a tensão, Foi utilizado como referência a dissertação de mestrado “Sistema de

baixo custo para monitoramento da geração de energia solar com conexão para internet

das coisas” do Ricardo Mazza Zago.

Nível 2 – Conectividade

A conectividade será feita através de uma rede de sensores sem fio (RSSF) com módulos

de comunicação BE900 e uma placa de desenvolvimento DK107 no nó sensor. Os módulos

de comunicação possuem o transceptor CC1101 e o microcontrolador ATmega328.

Nível 3 – Borda

O elemento de borda será uma Raspberry Pi 3, e ERB enviando os dados da comunicação

para o computador.

Nível 4 – Storage

Para o armazenamento de dados será utilizando um banco de dados relacional MySQL.

Nível 5 – Abstração

Na primeira etapa do projeto a abstração será realizada com a definição de limites para as

grandezas mensuradas. Os limites são determinados pelo especialista do negócio e pelos

fabricantes dos painéis fotovoltaicos. Se a potência medida estiver abaixo da especificada,

o alerta, então é emitido.

Nível 6 - Exibição

Para exibição dos dados foi desenvolvido um sistema web que possibilita consultar a

tensão, a corrente e a potência dos painéis solares. O sistema também realiza alertas

caso os valores das grandezas medidas não estejam dentro dos limites estabelecidos pelo

especialista do negócio.

## 3.3 Esquemas Elétricos

### 3.3.1 Materiais utilizados

Os materiais que são utilizados neste projeto são listados na Tabela 3.2.

Item | Uni | Quant | Descrição | Unitário | Total
1 | UN | 2 | Módulos de comunicação BE900 | R$ 180,00 R$ 360,00
2 | UN | 1 | UARTsBee | R$ 127,00 R$ 127,00
3 | UN | 2 | Antenas omnidireccional de 2,15 dBi | R$ 29,00 | R$ 58,00
4 | UN | 1 | Placa de desenvolvimento DK 107 | R$ 165,00 R$ 165,00
5 | UN | 1 | Raspberry Pi | R$ 290,00 R$ 290,00
6 | UN | 1 | Sensor Allegro ACS712 | R$ 26,90 | R$ 26,90
7 | UN | 1 | LM35 | R$ 10,90 | R$ 10,90

Tabela 3.2: Nível de ruído e resolução vs. Capacitância de filtragem e resolução de largura

de banda.

### 3.3.2 Descrição dos hardwares utilizados

O projeto do hardware implementado para o sistema de monitoramento solar teve como

base a necessidade de medição de variáveis específicas como, tensão, corrente e tempera-

tura. Dessa forma, foi projetada uma placa, com o auxílio do SATE na FEEC/Unicamp, para a implementação do circuito contendo o nó local sensor/atuador. Na placa estão

contidos dois resistores de precisão com 91 e 10 kΩs, respectivamente, um capacitor de

100 pF e um sensor de corrente Allegro ACS712. A descrição do sensor mencionado está

presente na subseção 3.3.3.

(a) Vista Superior | (b) Vista Inferior

Figura 3.8: Placa projetada para execução do monitoramento com a ajuda do SATE.

Os resistores presentes na placa estão associados de forma a criar um divisor de tensão

que tem por finalidade a medição da tensão gerada pelo painel solar. O objetivo do mesmo

consiste na redução do valor de tensão gerada pelo painel para o valor máximo de 5V, dito

máximo para utilização do Raspberry. A presença do capacitor se justifica como técnica

de redução de ruído, possibilitando medições mais precisas das variáveis.

A conectividade do sistema se deu com a utilização de uma RSSF. Nela, estão con-

tidos o módulo de comunicação BE900, que possui o microcontrolador ATmega328 e o

transceptor CC1101, e uma placa de desenvolvimento DK107, presente no nó sensor.

O BE900 foi escolhido por questões envolvendo o seu sistema de comunicação a rádio

e pela sua grande utilização em RSSF. Pode ser alimentado por tensões de 3, 3V até 5V e

foi implementado em Arduino. A sua faixa de operação é de frequência de 915 MHz para

a transmissão dos dados com uma potência de 10 dBm.

O Atmega328 é um microcontrolador de 8 bits com arquitetura Harvard modificada. É

produzido pela empresa Atmel, considerado na família megaAVR. Em relação a memória,

são 32 kB de memória flash, 1 kB de EEPROM e 2 kB de RAM. Dos 28 pinos, 23 são de

Input/Output, 32 registradores e 3 timers, sendo o timer0 e o timer2 de 8 bits e o timer1 de

16 bits. Possui serial programável USART, uma interface I2C, conversor A/D de 6 canais

e 10 bits, whatchdog timer interno programável com presença de oscilador e cinco modos

de energia por software. Opera entre 1, 8V e 5, 5V, alcançando taxa de transferência

de 1 MIPS (Millions of Instructions per Seconds) por MHz. Devido sua simplicidade,


Figura 3.9: Módulo de comunicação BE900.

baixa potência e ao baixo custo, é normalmente utilizado em projetos autônomos e mais

comumente implementado em Arduino (CAETANO, 2018).

O CC1101 é um transceptor de rádio sub-1GHz projetado para aplicações em redes sem

fio de baixa potência. É produzido para aplicações nas áreas científica, médica e indus-

trial. É integrado com modem de banda base altamente configurável, que suporta vários

formatos de configuração e possui taxa de dados configurável acima de 600 kbps. For-

nece suporte para hardware para manuseamento de pacotes, data buffering, transmissões

em rajada, indicação de qualidade do link e wake-on-radio. Seus principais parâmetros

são configurados via interface SPI e é tipicamente utilizado junto a um microcontrolador

(INSTRUMENTS, 2018).

Como elemento de borda do projeto foi utilizado um computador de plana única

Raspberry Pi 3. Sua escolha para utilização no projeto se deu por questões de custo

benefício. Ele possui um processador com quatro núcleos (Quad Core com 1,2GHz),

memória RAM de 1 GB, quatro portas ÚSB, além de entrada de cartão Micro SD para o

sistema operacional, Raspbian, e a realização da coleta de dados. Por meio de um script

em Python, o sistema operacional constrói o pacote da RSSF e realiza o tratamento dos

dados coletados.

Figura 3.10: Raspberry Pi 3.
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

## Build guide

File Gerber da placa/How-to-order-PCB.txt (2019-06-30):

How to Order PCB

Please refer to:
https://docs.easyeda.com/en/PCB/Order-PCB

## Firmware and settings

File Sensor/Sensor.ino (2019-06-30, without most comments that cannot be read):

// Radiuino_Sensor : firmware para os nos Sensores da rede

// Mais informacoes em www.radiuino.cc
// Copyright (c) 2015
// Author: Pedro Henrique Gomes, Omar C. Branquinho, Tiago T. Ganselli e Debora M Ferreira, Guilherme Lopes da Silva, Raphael Montali de Assumpçao. 
// Versao 2.3: 18/05/2017

// Este arquivo e parte da plataforma Radiuino
// Este programa e um software livre; voce pode redistribui-lo e/ou modifica-lo dentro dos termos da Licenca Publica Geral Menor GNU 
// como publicada pela Fundacao do Software Livre (FSF); na versao 2 da Licenca, ou (na sua opniao) qualquer futura versao.
// Este programa e distribuido na esperanca que possa ser  util, mas SEM NENHUMA GARANTIA; sem uma garantia implicita 
// de ADEQUACAO a qualquer MERCADO ou APLICACAO EM PARTICULAR. Veja a Licenca Publica Geral Menor GNU para maiores detalhes.
// Voce deve ter recebido uma copia da Licenca Publica Geral Menor GNU junto com este programa, se nao, escreva para a Fundacao 
// do Software Livre(FSF) Inc., 51 Franklin St, Fifth Floor, Boston, MA  02110-1301  USA
    
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
#include <RADIUINO.h>
#include <EEPROM.h>
#include <SPI.h>
#include <Monitorsolar.h>




#include "Headers.h"

#define FIRMWARE_VERSION   1.0     /* Versao 1.0 Radiuino */

byte int_rx = 0;
byte int_buff = 0;
Monitorsolar monitor(A0, A1, A3, 50);

unsigned long previousMillis = 0; 
const long interval = 600;  
/**
 * Configura o Arduino. Executado uma unica vez no inicio do firmware.
 */
void setup()
{  
  

  Phy.initialize();

  /* Inicializacao da camada de Controle de Acesso ao Meio */
  Mac.initialize();
  
  /* Inicializacao da camada de Rede */
  Net.initialize();
  
  /* Inicializacao da camada de Transporte */
  Transp.initialize();
  
  /* Inicializacao da camada de Aplicacao */
  App.initialize();
  
  /* Anexa as funcoes de interrupcao de recepcao de pacotes e de estouro de buffer de recepcao */
  attachInterrupt(0, IntReceiveData, RISING);
  attachInterrupt(1, IntBufferOverflow, RISING); 
  pinMode(GDO0, INPUT);

  /* Inicializa o Timer1 e configura o periodo para 1 segundo */
  Timer1.initialize(1000000);
  
  /* Anexa a funcao de interrupcao de estouro do Timer1 */
  Timer1.attachInterrupt(IntTimer1);  
  
  /* Escreve mensagem de inicializacao */
  //Serial.print("Radiuino! Sensor");

  /*Configura os pinos PD4 e PD6 como saída*/
  pinMode(IO0_PIN,OUTPUT);
  pinMode(IO2_PIN,OUTPUT);
  
  /*Aciona os LEDs que geralmente são ligados aos pinos PD4 e PD6*/
  digitalWrite(IO0_PIN,HIGH);
  digitalWrite(IO2_PIN,HIGH);
}
  
/**
 * Laco de execucao do Arduino. Executado continuamente.
 */
void loop()
{
    /* Verifica se deve entrar em modo Sleep */
  verifySleepEntering();
  unsigned long currentMillis = millis();
  if (currentMillis - previousMillis >= interval) {

    previousMillis = currentMillis;
  }  
}

/**
 * Trata o pacote recebido pela rede sem fio.
 */
void IntReceiveData()
{


  if (int_rx == 0) 
  {
    int_rx = 1;
    return;
  }
  
  /* Reenvia toda informacao recebida da rede para o PC */
  if ( digitalRead(GDO0) == HIGH ) 
  {      
    /* Recebe os dados do RF */
    Phy.receive(&g_pkt);      
  }
  
  return;
}

/**
 * Trata o estouro do buffer de recepcao.
 */
void IntBufferOverflow() 
{

  if (int_buff == 0) {
    int_buff = 1;
    return;
  }

  /* Esvazia o buffer de recepcao e vai para o estado de RX */  
  cc1101.Strobe(CC1101_SFRX);
  cc1101.Strobe(CC1101_SRX);
  
  return;  
}

/**
 * Trata o estouro do per�odo do Timer1.
 */
void IntTimer1()
{  
  /* Aqui podem ser colocadas tarefas peri�dicas. O per�odo do Timer1 � de 1 segundo por padr�o.
   * Mas pode ser mudado no setup() */  
  
  return;
}

/**
 * Realiza uma operacao Atomica para verificar se deve entrar no modo Sleep ou se deve sair do modo Sleep
 */
void verifySleepEntering ( void ) {
  ATOMIC_BLOCK(ATOMIC_FORCEON)
  {
    if (Mac.time_to_sleep > 0) {
    
      /* Aguarda o fim da tranmissao do ACK SLEEP */
      delayMicroseconds(500);
      while(Phy.txFifoFree() != CC1101_FIFO_SIZE);
    
      /* Entra em modo Sleep */   
      Phy.lowPowerOn();

    }
    else if (Mac.time_to_sleep == 0) {

      /* Habilita o conversor AD */
      _SFR_BYTE(ADCSRA) |= _BV(ADEN);
      
      /* Saindo do modo de Sleep */
      cc1101.Strobe(CC1101_SIDLE);
      delay(1);
      cc1101.Strobe(CC1101_SFTX);
      cc1101.Strobe(CC1101_SFRX);
      cc1101.Strobe(CC1101_SRX);
    
      Mac.time_to_sleep = -1;
      Mac.last_wakeup = millis();
    }

    if ((Mac.flag_sleep2)&&(Mac.time_to_sleep < 0)){
      if( (millis() - Mac.last_wakeup) >= Mac.t2){
         Mac.time_to_sleep = Mac.t3;
      }
    }
  }
}

/**
 * Interrupcao de WatchDog. Executada sempre que o contador de WatchDog estoura
 */
ISR(WDT_vect) {

  /* Verifica se precisamos decrementar o contador de Sleep */
  if (Mac.time_to_sleep > 0) {
    Mac.time_to_sleep--;
    return;
  }
  
}

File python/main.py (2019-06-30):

import serial
from raduino import Raduino, Response, Sensores
from dao import MedicaoDAO, FalhaDAO, ClienteDAO
from model import Medicao, Falha
from whatsapp import Whatsapp
from myemail import SendMail
import zope.event
import time
from datetime import datetime
import termios

ID_SENSOR = 1               #armazena o ID da planta
medicoes = []               #medicoes realizadas, antes de inserir no banco
num_leituras = 3            #número de leituras a ser realizadas
totalPacotesPerdidos = 0    #numero máximo de pacotes perdidos para relatar uma falha
tempo_maximo_para_atualizar = num_leituras * 2
contador_medicoes = 0

#loop principal      
def conectar():
    perda_pacotes = 0
    global totalPacotesPerdidos
    try:
        raduino = Raduino("/dev/ttyUSB0", ID_SENSOR)  #cria um objeto raduino que recebe dados do sensor
        while True:
            res = raduino.request()                   #faz um request solicitando dados do sensor
            if (res):
                zope.event.notify(res)                #informa aos inscritos que os dados do sensor chegaram
                time.sleep(1)                         
                perda_pacotes = 0
                totalPacotesPerdidos = 0
            else:
                totalPacotesPerdidos = totalPacotesPerdidos + 1
                perda_pacotes = perda_pacotes + 1
                if (perda_pacotes > 5):
                    enviar_notificacao(ID_SENSOR, "Muitos pacotes estao sendo perdidos", 'Problemas na comunicação')
                    raduino.close()                   #fecha raduino
                    conectar()                        #(recuperacao de falha) reconecta caso tenha varias perdas de pacotes                    
                if (totalPacotesPerdidos > 10):       #após 10 pacotes perdidos envia notificacao por email
                    enviar_notificacao(ID_SENSOR, "A base nao consegue se conectar com os sensores", 'Falha de comunicação')
                    exit()
    except KeyboardInterrupt:        
        raduino.close()
    except termios.error:
        enviar_notificacao(ID_SENSOR, "A base nao consegue se conectar com os sensores", 'Falha de comunicação')
    except serial.SerialException as e:
        enviar_notificacao(ID_SENSOR, "A base nao consegue se conectar com os sensores", 'Falha de comunicação')


#adiciona inscritos - funcões que esperam a resposta 
#do nó sensor para realizar processamento
def add_subscribes():
    zope.event.subscribers.append(log)
    zope.event.subscribers.append(registra_medicao)

##leitura de dados do raduino
def log(res):
    tensao = res.get(Sensores.TENSAO)
    corrente = res.get(Sensores.CORRENTE)
    temperatura = res.get(Sensores.TEMPERATURA)
    print("Tensao ", tensao, " Corrente ", corrente, "Temperatura", temperatura, "RSSIu", res.rssiu, "RSSIi", res.rssid)

#faz media dos valores lido
def registra_medicao(res):
    global medicoes
    global contador_medicoes
    contador_medicoes = contador_medicoes + 1
    tensao = res.get(Sensores.TENSAO)
    #corrente = 1
    corrente = res.get(Sensores.CORRENTE)    
    temperatura = res.get(Sensores.TEMPERATURA)
    luminosidade = 0
    tempo = datetime.now()
    medicao = Medicao(ID_SENSOR, tensao, corrente, temperatura, luminosidade, tempo, res.rssid, res.rssiu)
    
    if (len(medicoes) == 0 or medicao != medicoes[-1]):
        medicoes.append(medicao)
        dao = MedicaoDAO()
        dao.atualizar(medicao, ID_SENSOR)          # atualiza a medica
    
    ##se o vetor de medicoes foi preenchido ou se apos o tempo determinado não foi possivel preencher o vetor
    #atualiza a informação no banco de dados
    if(len(medicoes) == num_leituras or contador_medicoes == tempo_maximo_para_atualizar): 
        contador_medicoes = 0
        media_medicao = calcula_media_medicoes()
        save(media_medicao)                                   #registra a medicao no banco
        verificar_falhas(media_medicao)                       #verifica se houve falha 

def calcula_media_medicoes():
    global medicoes 
    saveMedicao = medicoes.pop(0)
    for potencia in medicoes:
        #somatorio das medidas
        saveMedicao.tensao = saveMedicao.tensao + potencia.tensao
        saveMedicao.corrente = saveMedicao.corrente + potencia.corrente
        saveMedicao.potencia = saveMedicao.potencia + potencia.potencia
        saveMedicao.temperatura = saveMedicao.temperatura + potencia.temperatura
        saveMedicao.luminosidade = saveMedicao.luminosidade + potencia.luminosidade
    #faz a media    
    #n_medidas = len(medicoes) if len(medicoes) != 0 else 1
    saveMedicao.tensao = saveMedicao.tensao / num_leituras 
    saveMedicao.corrente = saveMedicao.corrente / num_leituras
    saveMedicao.potencia = saveMedicao.potencia / num_leituras
    saveMedicao.temperatura = saveMedicao.temperatura / num_leituras 
    saveMedicao.luminosidade = saveMedicao.luminosidade / num_leituras
    medicoes.clear()
    return saveMedicao


#salva no banco de dados
def save(medicao):    
    dao = MedicaoDAO()
    dao.inserir(medicao)

#verifica se houve falhas
def verificar_falhas(medicao):    
    dao = FalhaDAO()   
    potencia_minima =  dao.get_potenciaMinima(ID_SENSOR)
    print("Potencia minima", potencia_minima)
    if (medicao.potencia <= potencia_minima):
        print("Ocorreu uma falha", potencia_minima)
        msg = "A potência dos paineis esta abaixo do mínimo."
        enviar_notificacao(ID_SENSOR, msg, 'Falha na usina solar',medicao) 
           

#envia notificacoes de falha pelo whatsapp, email e registra no banco
def enviar_notificacao(sensor, msg, categoria, medicao = None):
    clienteDao = ClienteDAO()
    contato = clienteDao.get_contato(sensor)
    toemail = contato[0]
    fone = contato[1]

    if(fone):
        print('mensagem enviada whatsapp')
        #whats = Whatsapp()
        #whats.send(str(fone), msg)

    if(toemail):
        print('email enviado')
        semail = SendMail()
        semail.send( toemail, "Falha sistema monitoramento solar", msg)

    dao = FalhaDAO()
    falha = Falha(ID_SENSOR, msg, datetime.now(), categoria)
    dao.inserir(falha)

    #faz a medicao ser 0 houver erro
    if(medicao is None):
        tempo = datetime.now()
        medicao = Medicao(ID_SENSOR, 0, 0, 0, 0, tempo, 0, 0)  
    
    dao = MedicaoDAO()
    dao.atualizar(medicao, ID_SENSOR)  

#inicio
add_subscribes()
conectar()

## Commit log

2019-05-14 skecth arduino e fotos
2019-06-30 adicionando front-end php, source em python da elemento de borda e bibliotecas e firmware dos sensores, além do projeto da placa
    [Gerber_BoardOutline.GKO, Gerber_BottomLayer.GBL, Gerber_BottomSolderMaskLayer.GBS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]
2019-07-05 Adicionando relatório revisado e link de video no youtube

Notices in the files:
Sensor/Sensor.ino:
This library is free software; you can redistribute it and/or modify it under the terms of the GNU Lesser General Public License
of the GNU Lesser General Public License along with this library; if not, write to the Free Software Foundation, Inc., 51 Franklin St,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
